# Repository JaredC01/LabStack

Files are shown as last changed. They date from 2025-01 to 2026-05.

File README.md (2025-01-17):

# LabStack
Modular rackmount solutions for Raspberry Pi's and other SBC's and accessories.

#### Hey Everyone!
Just to keep everyone in the loop, I will continue to work on uploading instructions and images as I have time.  In the meantime, all of the current STLs are available!

**NOTE: Additional hardware IS required for most models.**

Here's a short list of hardware off the top of my head:
* 2U Printed Bracket - Requires 16x M3x4x5mm Brass Heatset Inserts, 4x M3x6mm (or other M3x6mm thru M3x20mm) screws per module (BHCS or SHCS, no FHCS).
* 1U 5.25" Drive Bay Mount (designed specifically for the Icy Dock ExpressCage MB324SP-B) - Requires 8x M3x6mm screws (BHCS or SHCS, no FHCS).
* General Pi Mounts (2x Pi, 1x Pi, etc.) - Requires 4x M2.5x5 SHCS screws.  If using a HAT (PoE or otherwise), standoffs and/or other length M2.5 screws may be required.
* JetKVM Modules - Requires 2x M2x12 SHCS screws per JetKVM unit.
* 80mm Fan Panel - Requires the coarse-thread screws that the fans come with.

**I am open to helping create mounts for specific models within reason, but will be releasing CAD for users to create their own mounts!  The possibilities are endless!**

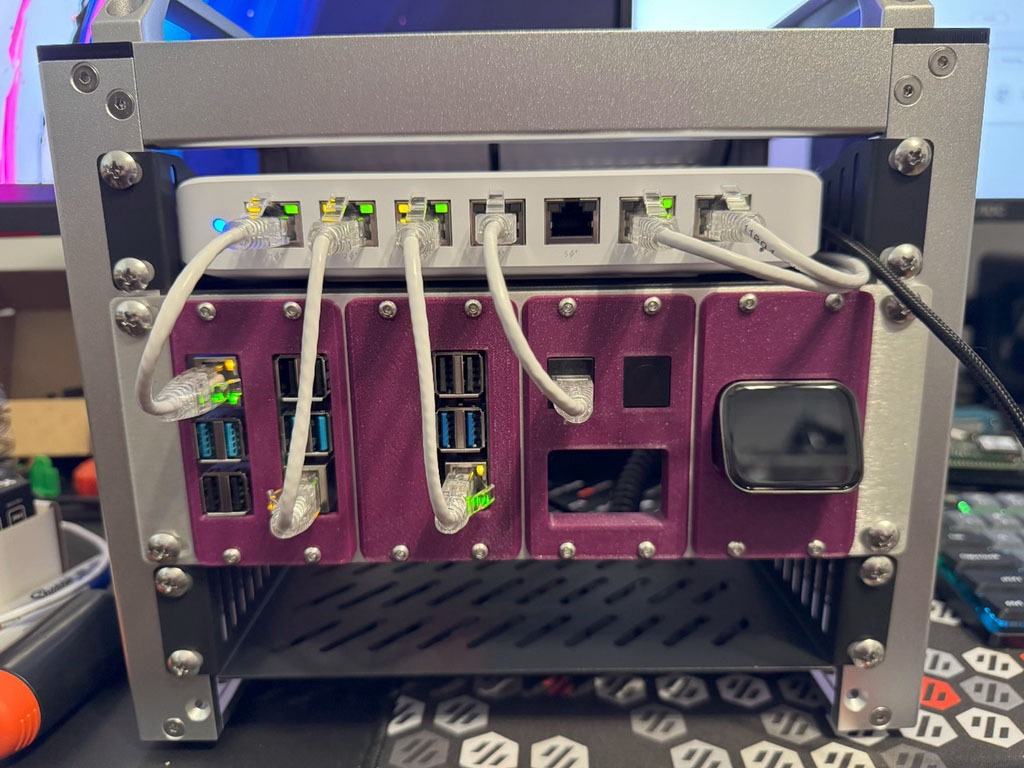
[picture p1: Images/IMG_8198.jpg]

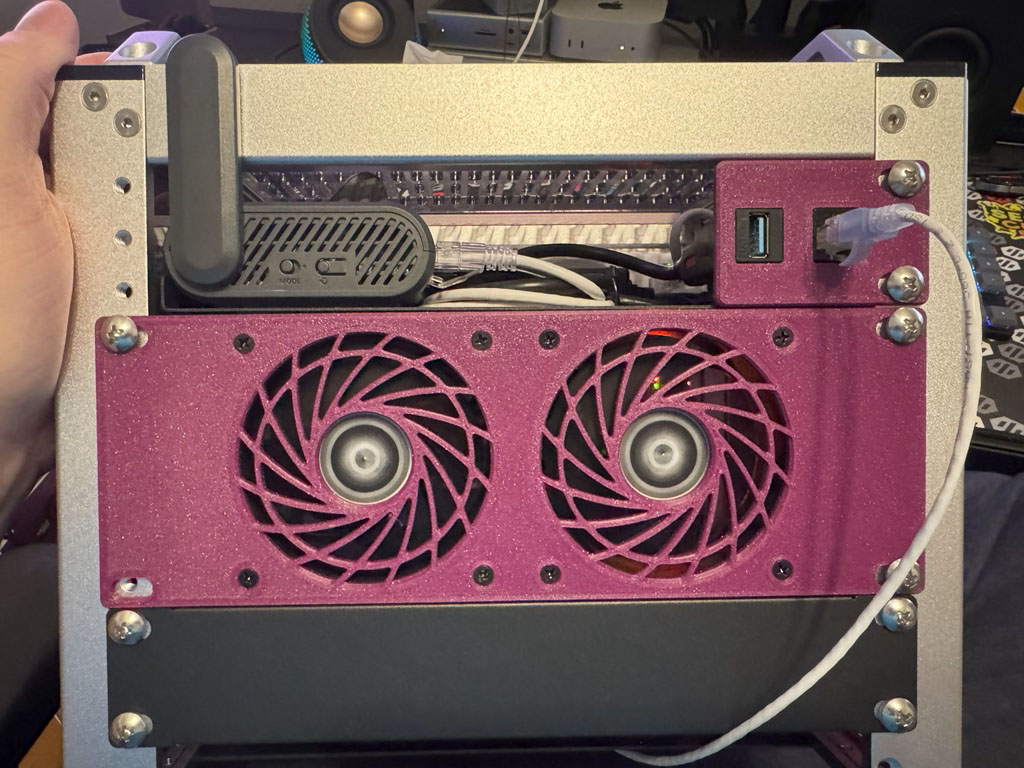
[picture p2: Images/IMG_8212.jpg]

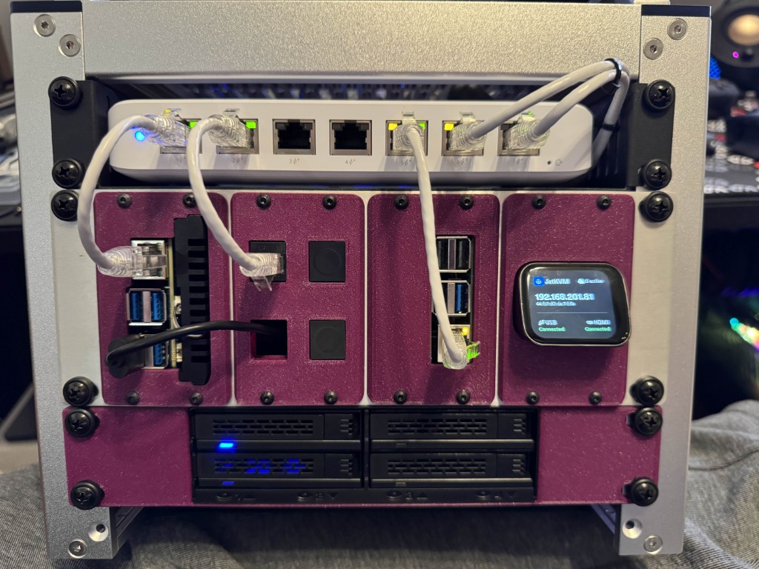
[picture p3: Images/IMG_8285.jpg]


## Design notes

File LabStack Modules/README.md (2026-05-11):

# LabStack Modules
This section of the repository contains 3D models of items that mount into LabStack *brackets* (see the [LabStack 19](https://github.com/JaredC01/LabStack/tree/main/LabStack%2019) and [LabStack Mini](https://github.com/JaredC01/LabStack/tree/main/LabStack%20Mini) sections in the directory above this one). Each module consumes a single slot in those brackets, allowing up to four modules (eight in a 19" rack) to be mounted side-by-side while requiring only 2U of height. A brief description of each item is given in the following tables:

## STLs

| **File** | **Description** | **Hardware Required** |
| :--- | :--- | :--- |
| `Module 1x JetKVM 1x Keystone 90 Degree.stl` | Mounts a JetKVM + one keystone slot | Two M2 x 16mm SHCS |
| `Module 1x JetKVM 2x Keystone.stl` | Mounts a JetKVM + two keystone slots | Two M2 x 16mm SHCS |
| `Module 1x JetKVM.stl` | Mounts a JetKVM | Two M2 x 16mm SHCS |
| `Module 1x JetKVM with Logo.stl` | Mounts a JetKVM. Has embossed logo at rack face | Two M2 x 16mm SHCS |
| `Module 1x Pi 1B Rev 2.0.stl` | Mounts one old-school Raspberry Pi 1 Model B | Two M2 screws, two M2 nuts |
| `Module 1x Pi 5 with Pimoroni NVMe Base.stl` | Mounts one Pi 5 with the [Pimoroni NVMe Base](https://shop.pimoroni.com/products/nvme-base) underneath | Hardware from Pimoroni kit |
| `Module 1x Pi 5 with Pimoroni NVMe Base Tall.stl` | Same as above, but allows using the taller standoffs to put the Pi "higher" above the base | Same as above |
| `Module 1x Pi 5 with WisdPi 5Gbps HAT.stl` | Mounts one Pi 5 with the [WisdPi 5GbE PoE Hat](https://www.wisdpi.com/products/wp-nh5000p) | Hardware from WisdPi kit |
| `Module 1x Pi with 25 SSD.stl` | Mounts one Pi and one 2.5" SSD (max 9mm thick) underneath. SDD's SATA ports are exposed at rack face | Four M3 screws, four M2.5 screws + heatsets |
| `Module 1x Pi with 2x Keystone.stl` | Mounts one Pi + two keystone slots | Four M2.5 screws + heatsets |
| `Module 1x Pi with HAT.stl` | Mounts one Pi, has a blank panel to be modified for any HAT | Four M2.5 screws + heatsets |
| `Module 1x WaveShare CM4-IO-BASE with HAT.stl` | Mounts one Pi CM4 in the [WaveShare Mini Base Board](https://www.waveshare.com/wiki/CM4-IO-BASE-B) | Hardware from WaveShare kit |
| `Module 2x 25 SSD.stl` | Mounts two 2.5" drives, with their SATA ports exposed at rack face | Four M3 screws per drive |
| `Module 2x JetKVM.stl` | Mounts two JetKVM units in a single module | Four M2 x 16 SHCS |
| `Module 2x Keystone.stl` | A blanking plate with two keystone slots | None |
| `Module 2x Keystone with Passthru.stl` | A blanking plate with two keystone slots and a generic pass-through opening | None |
| `Module 2x Pi.stl` | Mounts two Raspberry Pis, without additional fans (see subsection below) | Eight M2.5 screws, four M 2.5 heatsets |
| `Module 3x 25 SSD.stl` | Mounts three 2.5" drives, with their SATA ports exposed at rack face. Maximum thickness ~9mm per drive | Four M3 screws per drive |
| `Module 4x Keystone.stl` | A blanking plate with four keystone slots | None |
| `Module Blank.stl` | A completely blank plate. Can be modified for custom designs | None |
| `Module WaveShare 2.8in DSI Display.stl` | Mounts the [WaveShare 2.8" DSI Display](https://www.waveshare.com/wiki/2.8inch_DSI_LCD) | Liquid/gel adhesive (optional) |

## STLs/Module 2x Pi with Fan

This module assembly mounts two Raspberry Pis (any modern Pi with a "B" footprint should fit) in a single module slot, along with blower fan(s) to increase airflow across them.

| **File** | **Description** |
| :--- | :--- |
| `Module 2x Pi with Fan.stl`  | Main body. Includes mount points for a fan bracket (below) |
| `4010 Axial Mount.stl` | Mounts a single 40x10mm blower fan such that it blows air for both Pis |
| `Dual 3007 Blower Mount.stl` | Mounts one 30x7mm blower fan for each Pi |
| `Dual 4010 Blower Mount.stl` | Mounts one 40x10mm blower fan for each Pi |

## STLs/Module Radxa X4

This module assembly mounts a [Radxa X4](https://radxa.com/products/x/x4) mini-PC. Required hardware:
 - The X4 and its included heatsink/blower fan (but not the leg frame that comes attached)
 - Four M2.5 x 25mm socket-headed cap screws (SCHS)
 - One 3D printed body (top row of table below) 
 - Four 3D printed spacers (see table below)
 - (Optional) Power-over-Ethernet hat

The module is assembled as a stack, listed from bottom to top here: printed body, PoE hat (if present), printed spacer, X4, heatsink/blower fan. The printed spacer should be used on the screw that is farthest from the rack face, closest to the L-shaped shelf of the printed body. Screw through the stack and into the heatsink's tapped holes.

| **File** | **Description** |
| :--- | :--- |
| `Module 1x Radxa X4 with Heatsink.stl` | Main body. Includes a hexagonal cutout for PoE hat's fan |
| `Radxa X4 NO PoE HAT Spacer.stl` | Spacers to use when NOT using PoE hat |
| `Radxa X4 WITH PoE HAT Spacer x4.stl`  | Spacers to use when PoE hat is installed |

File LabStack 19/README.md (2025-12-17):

# Labstack 19
This section of the repository contains models of items that mount directly to a **full-width** (19") rack. Currently, the only item inside is `DXFs/2U 19 Lasercut Bracket.dxf`, which is a 2D design for a bracket to be laser- or plasma-cut. It is 2U tall and can hold a total of **eight** "LabStack Modules" (see the [Modules](https://github.com/JaredC01/LabStack/tree/main/LabStack%20Modules) section in the directory above this one).

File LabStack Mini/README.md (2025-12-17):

# LabStack Mini System
This section of the repository contains 3D models of items that mount directly to a half-width (10") mini-rack. The most important is probably the **Brackets** directory, which has several modules that can each accept four "LabStack Modules" (see the [Modules](https://github.com/JaredC01/LabStack/tree/main/LabStack%20Modules) section in the directory above this one). A simple description of each file in that folder is given in the following table:

## Brackets

| **File** | **Description** |
| :--- | :--- |
| `DXFs/2U Mini Lasercut Bracket.dxf` | A 2D design for a bracket to be laser-cut instead of 3D-printed. |
| `STLs/2U Mini 4x LabStack Module M3 Nut Bracket.stl` | Full-width 3D printable bracket that uses standard M3 hex nuts (4/module). |
| `STLs/2U Mini 4x LabStack Module M3x3x4.6mm Heatset Bracket.stl` | Full-width 3D printable bracket that uses M3x3x4.6 heatset inserts instead of nuts. |
| `STLs/2U Mini 4x LabStack Module M3x4x5mm Heatset Bracket.stl` | Full-width 3D printable bracket that uses M3x4x5 heatset inserts instead of nuts. |
| `STLs/2U Mini Split 4x LabStack Module Bracket x2.stl` | Half-Width 3D printable bracket for smaller printers. Requires 2x printed parts and heatsets. |

## Accessories

The **Accessories/STLs** directory contains rack-mount options for items that may not fit in a module as easily, such as larger Mini-PCs, or for alternate companions for the `2U Mini Split 4x LabStack Module Bracket x2.stl` described above ("half-width brackets"). All items in this table are 3D printable.

| **File** | **Description** |
| :--- | :--- |
| `1.5U Mini 1x M4 Mac Mini with 1x LabStack Bracket Left.stl`  | A 1.5U bracket that holds an M4 Mac Mini (left) with a LabStack module (horizontal). |
| `1.5U Mini 1x M4 Mac Mini with 1x LabStack Bracket Right.stl` | A 1.5U bracket that holds an M4 Mac Mini (right) with a LabStack module (horizontal). |
| `1U Mini 2x Keystone 2x SMA Left Mount.stl` | A half-width bracket for 2x keystone slots nearest the rail, 2x SMA ports by center. |
| `1U Mini 2x Keystone 2x SMA Right Mount.stl` | Same as above, but can be mounted on opposite rail without keystones upside-down. |
| `1U Mini 2x Keystone Left Mount.stl` | A **quarter-width** bracket for 2x keystone slots. Useful for cable management. |
| `1U Mini 2x Keystone Right Mount.stl` | Same as above, but can be mounted on opposite rail without keystones upside-down. |
| `1U Mini 525 Drive Bay Mount.stl` | A full-width bracket with a single 5.25" drive bay, such as for a CD or DVD drive. |
| `1U Mini Blank Panel.stl` | A full-width blanking panel. Can be used to manage airflow/aesthetics, or base for new designs. |
| `2U Mini 2x 80mm Fan Panel.stl` | 2U full-width blanking panel, with holes and a grate for mounting two 80mm fans. |
| `M4 Mac Mini Spacer x2.stl` | A companion piece for the M4 Mac Mini brackets (top two rows), supports top/bottom shelves. |
| `Split Bracket Brace x2.stl` | A companion piece for half-width brackets, used to join two halves together. |

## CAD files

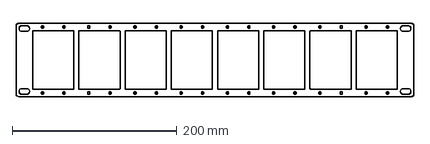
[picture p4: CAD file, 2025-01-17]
LabStack 19/Brackets/DXFs/2U 19 Lasercut Bracket.dxf
482.6 x 89.0 mm

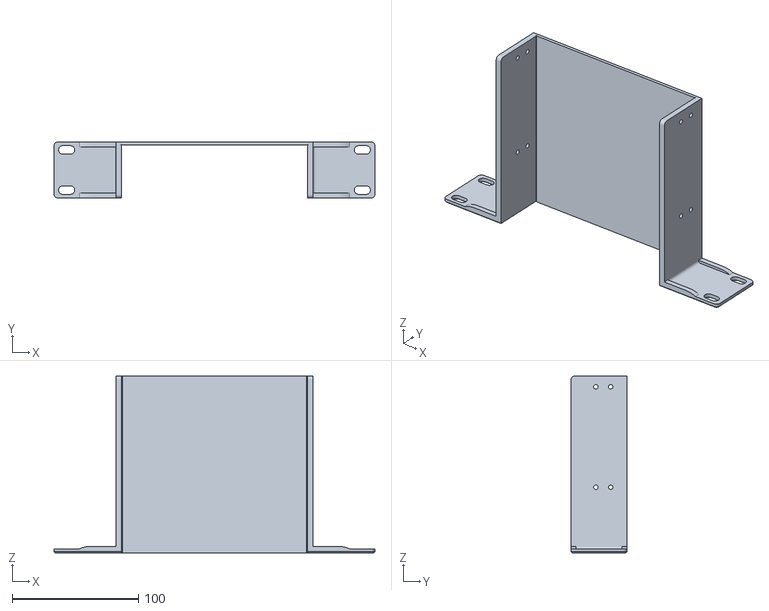
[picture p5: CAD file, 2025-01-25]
LabStack Mini/Accessories/STLs/1U Mini 525 Drive Bay Mount.stl
254.0 x 44.4 x 140.0

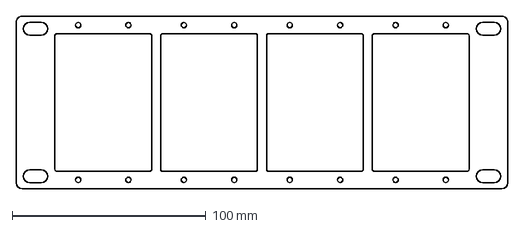
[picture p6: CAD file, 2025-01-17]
LabStack Mini/Brackets/DXFs/2U Mini Lasercut Bracket.dxf
254.0 x 89.0 mm

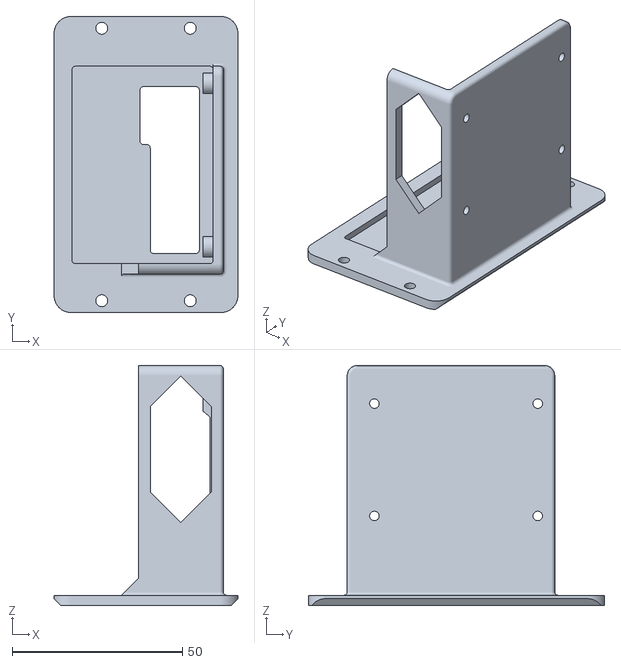
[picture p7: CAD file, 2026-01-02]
LabStack Modules/STLs/Module 1x Waveshare 30915.stl
54.0 x 87.0 x 70.5

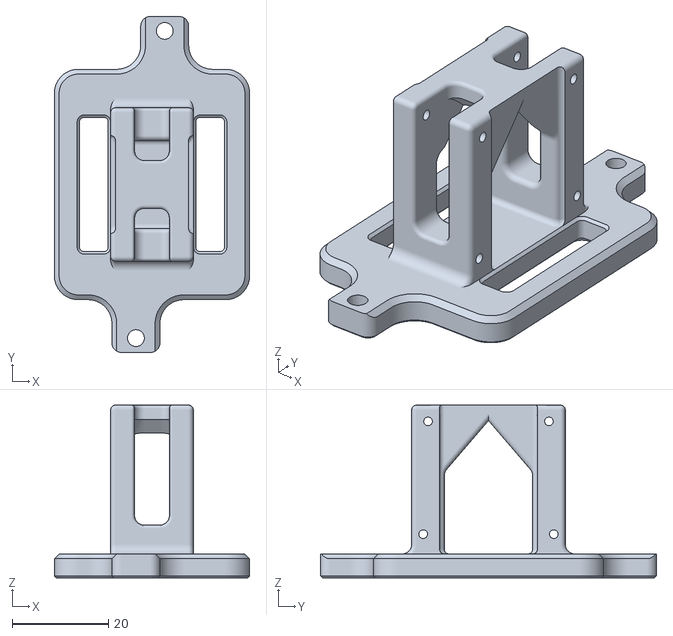
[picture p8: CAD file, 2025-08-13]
LabStack Modules/STLs/Module 2x Pi with Fan/Dual 3007 Blower Mount.stl
40.7 x 70.0 x 36.0

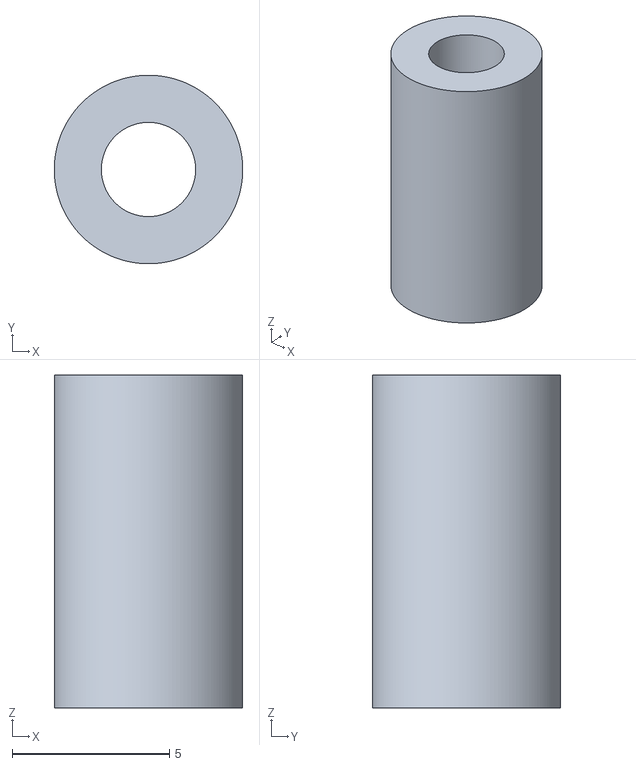
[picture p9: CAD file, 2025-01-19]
LabStack Modules/STLs/Module Radxa X4 with Heatsink/Radxa X4 NO PoE HAT Spacer x4.stl
6.00 x 6.00 x 10.6

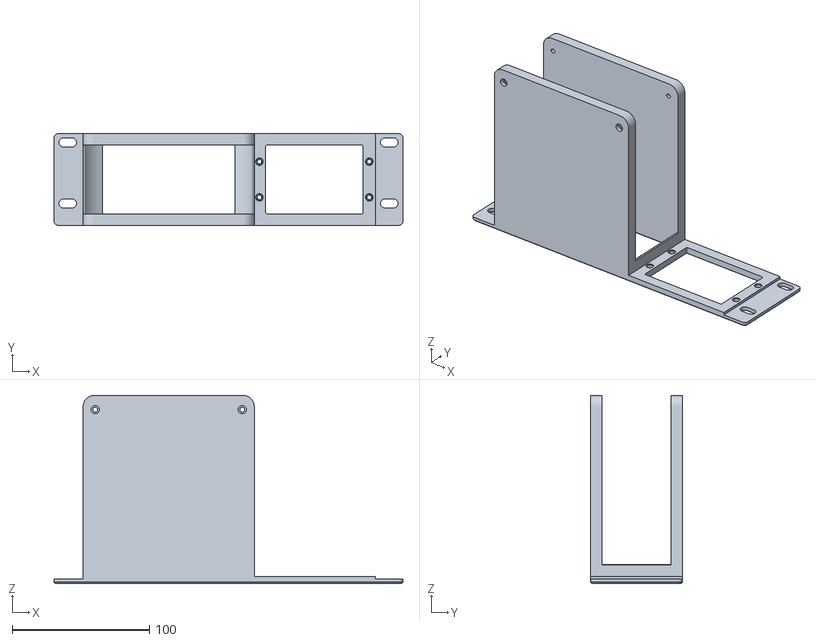
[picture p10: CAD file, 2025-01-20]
LabStack Mini/Accessories/STLs/1.5U Mini 1x M4 Mac Mini with 1x LabStack Bracket Right.stl
254.0 x 66.7 x 137.0

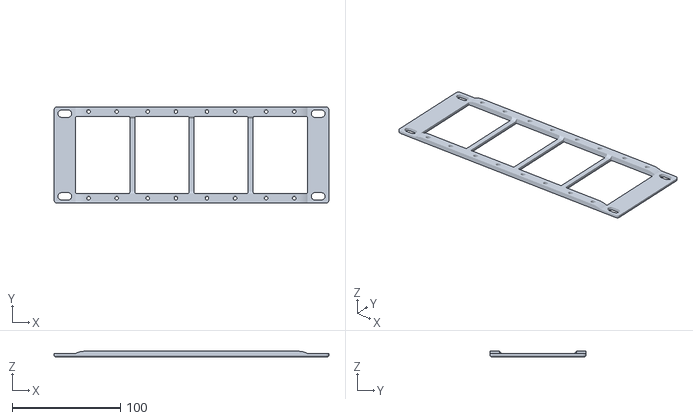
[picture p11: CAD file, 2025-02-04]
LabStack Mini/Brackets/STLs/2U Mini 4x LabStack Module M3x3x4.6mm Heatset Bracket.stl
254.0 x 89.0 x 5.20

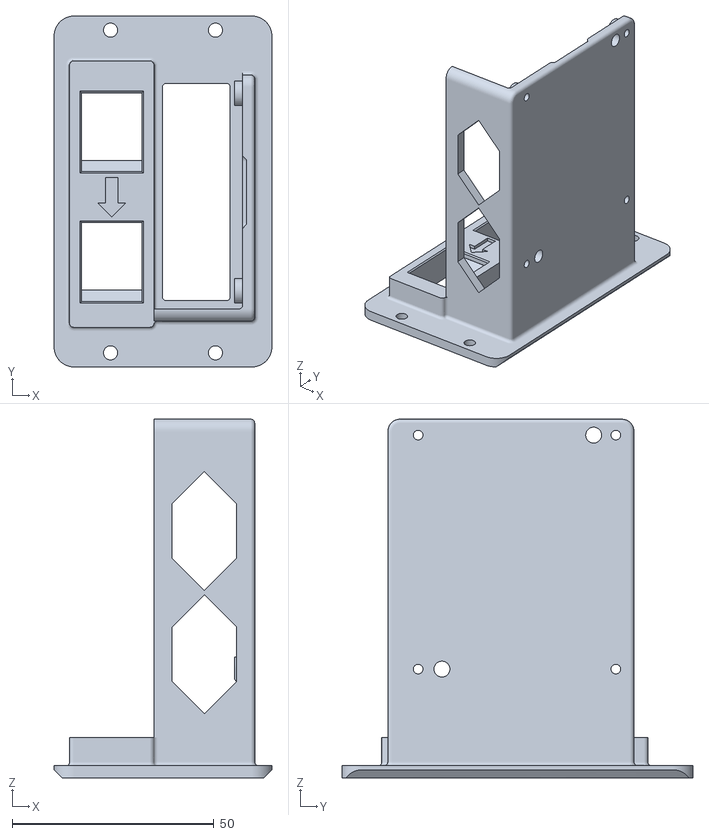
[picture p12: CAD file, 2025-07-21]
LabStack Modules/STLs/Module 1x Pi with 2x Keystone.stl
54.0 x 87.0 x 88.9

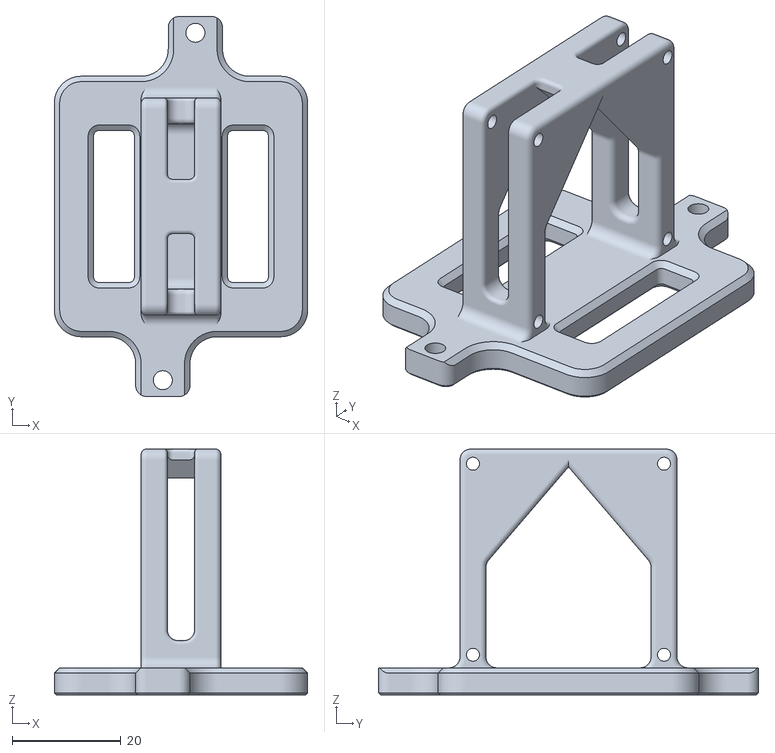
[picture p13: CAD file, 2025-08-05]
LabStack Modules/STLs/Module 2x Pi with Fan/Dual 4010 Blower Mount.stl
46.7 x 70.0 x 45.3

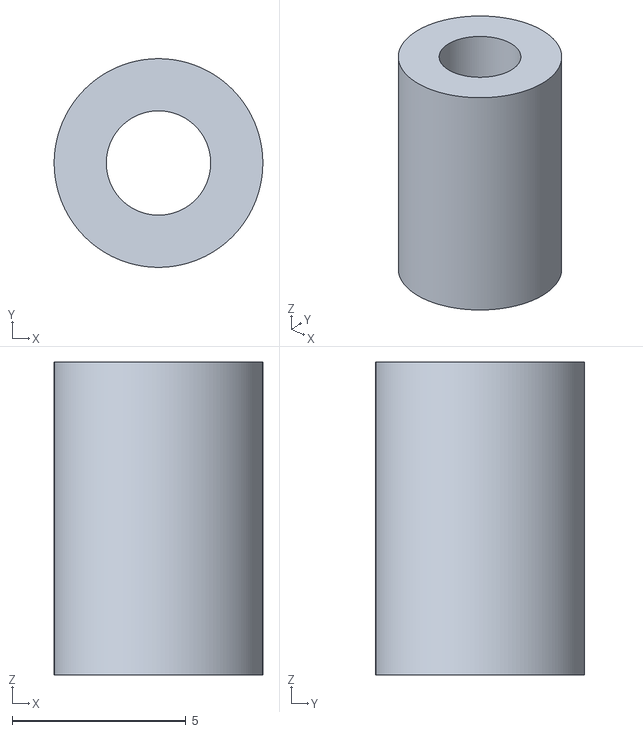
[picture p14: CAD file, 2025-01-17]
LabStack Modules/STLs/Module Radxa X4 with Heatsink/Radxa X4 WITH PoE HAT Spacer x4.stl
6.00 x 6.00 x 9.00

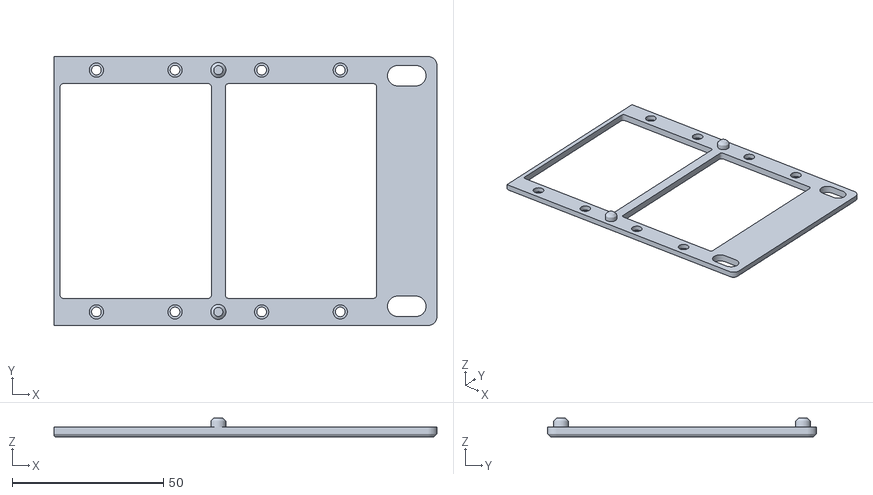
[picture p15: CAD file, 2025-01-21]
LabStack Mini/Brackets/STLs/2U Mini Split 4x LabStack Module Bracket x2.stl
126.7 x 89.0 x 6.20

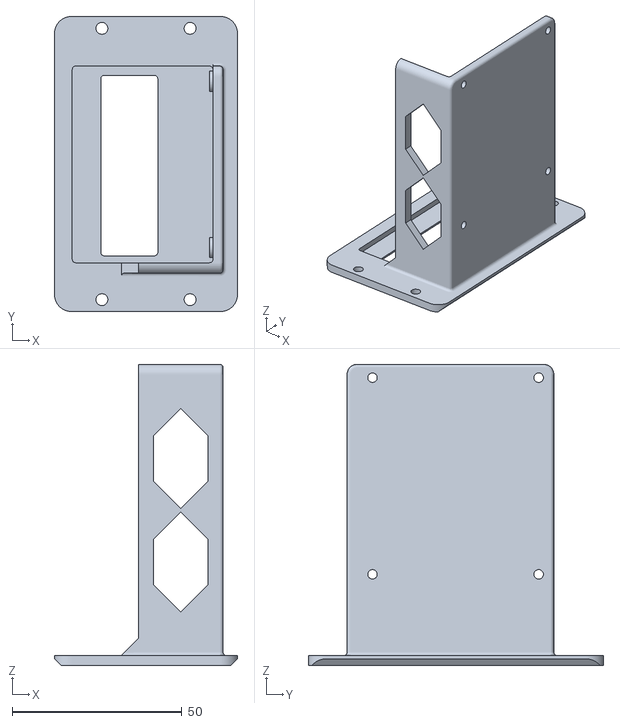
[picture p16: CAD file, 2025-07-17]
LabStack Modules/STLs/Module 1x Pi 5 with Pimoroni NVMe Base Tall.stl
54.0 x 87.0 x 88.9

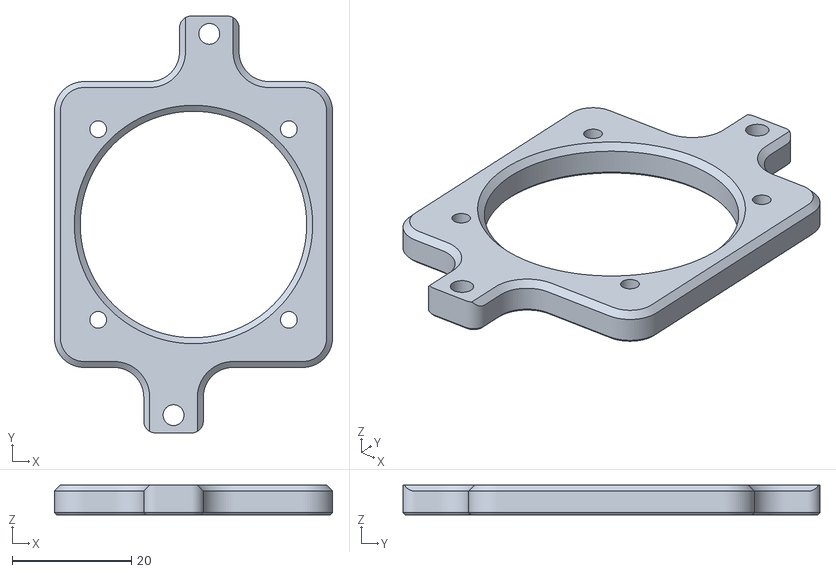
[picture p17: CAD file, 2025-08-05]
LabStack Modules/STLs/Module 2x Pi with Fan/4010 Axial Mount.stl
46.7 x 70.0 x 5.00

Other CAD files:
LabStack Mini/Accessories/STLs/1.5U Mini 1x M4 Mac Mini with 1x LabStack Bracket Left.stl
LabStack Modules/STLs/Module Radxa X4 with Heatsink/Module 1x Radxa X4 with Heatsink.stl
LabStack Mini/Accessories/STLs/M4 Mac Mini Spacer x2.stl
LabStack Mini/Brackets/STLs/2U Mini 4x LabStack Module M3x4x5mm Heatset Bracket.stl
LabStack Mini/Accessories/STLs/1U Mini 2x Keystone 2x SMA Left Mount.stl
LabStack Mini/Accessories/STLs/1U Mini 2x Keystone 2x SMA Right Mount.stl
LabStack Mini/Accessories/STLs/1U Mini 2x Keystone Left Mount.stl
LabStack Mini/Accessories/STLs/1U Mini 2x Keystone Right Mount.stl
LabStack Mini/Accessories/STLs/1U Mini Blank Panel.stl
LabStack Mini/Accessories/STLs/2U Mini 2x 80mm Fan Panel.stl
LabStack Mini/Accessories/STLs/Split Bracket Brace x2.stl
LabStack Mini/Brackets/STLs/2U Mini 4x LabStack Module M3 Nut Bracket.stl
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

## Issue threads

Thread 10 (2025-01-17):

module suggestion

ConanWolf46, 2025-01-17:
https://www.amazon.com/dp/B01J705MTC?ref=ppx_yo2ov_dt_b_fed_asin_title&th=1

this amazon product is a sim data to USB for internet via phone service, there is a version of the product on aliexpress as well however i only linking amazon because idk how people feel about aliexpress on here, the version on aliexpress is 9 USD.

the module idea that i was having was similarly to the antenna coming out of the back but for the device, the USB port on the device is in the front (antenna is in the back) making it perfect for that 4 hole module setup that you have already

JaredC01, 2025-01-17:
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

Just so I'm clear, you're looking for a way to mount this device in a module at the front of the LabStack, correct?  Are you wanting to break out the USB port as well via Keystone Jack?

bemany, 2025-01-21:
Request for Intel Nuc BOXNUC8i5BEK2

I am not able to find a simple solution for mounting the nuc on its mounting screws on a 10" module

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
https://www.intel.com/content/www/us/en/support/articles/000006857/intel-nuc/intel-nuc-kits.html

It would also be nice to ziptie the power adapter next to it "huntkey HKA09019047-6u"
https://www.ebay.de/itm/256636100141

Break out of HDMI, Keystone .. is not mandatory

ConanWolf46, 2025-02-16:
hay sorry for not responding for a bit, ideally yes because this device requires a USB connection and the goal is for a raspberry pi server over a phone network

ConanWolf46, 2025-02-16:
after the pi gets the network via the device, i could if i wanted to split the network off to multiple other pis if needed or just have the one pi as needed.

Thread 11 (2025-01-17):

ODroid-H2/3/4

jar349, 2025-01-17:
I have a bunch of the [H-series odroids (H2, H3, H4)](https://www.hardkernel.com/shop/odroid-h4/) that it would be awesome to mount into a 10" mini-rack!

I'm opening this issue to see if others would also be interested.

JaredC01, 2025-01-17:
With the size on these being 120mm x 120mm, they would need to be in a full 1U mount rather than a module.  As with the Zimaboard, I could make one with a JetKVM mount included, but that's probably the only option available for it.

jar349, 2025-01-25:
With 1U of space, 10" wide, I wonder if two odroids could be mounted side by side?

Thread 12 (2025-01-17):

Module for RPI 1

oNutti, 2025-01-17:
Hello,
I currently run RPI 4, RPI 1 and a switch, and half a patch panel. This project is perfect for me, i would just love to have a mount for RPI 1.

JaredC01, 2025-01-17:
Does the RPi 1 not use the same mount as the rest of the Pi's?  I'm not familiar with the older Pi's, but I thought they shared the same form factor as the newer ones.  A single 2x Pi mount should fit both your Pi 4 and your Pi 1 (with 3 modules open for other things).

oNutti, 2025-01-17:
> Does the RPi 1 not use the same mount as the rest of the Pi's? I'm not familiar with the older Pi's, but I thought they shared the same form factor as the newer ones. A single 2x Pi mount should fit both your Pi 4 and your Pi 1 (with 3 modules open for other things).

Unfortunately, not. The RPI 1 (maybe 2?) uses other mounting holes, actually only two. The 3, 4, 5 (maybe 2) uses the same holes. It's one of the dumbest things, they made..

oNutti, 2025-01-17:
Yes, the RPI 1 is can't be more outdated, but i still use it for hosting local controllers - someone other than me, might also use it, haha.

JaredC01, 2025-01-17:
I'm guessing it's more to do with the model "B" being the same (it looks like there's a Pi 1 Model B that looks to be the same as the rest). Do you have a picture of the Pi 1 you have for reference to know what I'm looking for?

oNutti, 2025-01-17:
The RPI 1 model B+ use the same mounting holes as the other ones, but funny enough does the RPI 1 use some other ones.

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

JaredC01, 2025-01-17:
Too many letters and pluses! 🤣

I should be able to find a model for that Pi 1 and add a mount for it, but I don't expect I'll be able to make it work with a dual-Pi mount (meaning it would be a single module unit). So long as that's not an issue, I'll add it to the list!

oNutti, 2025-01-17:
> Too many letters and pluses! 🤣
>
> I should be able to find a model for that Pi 1 and add a mount for it, but I don't expect I'll be able to make it work with a dual-Pi mount (meaning it would be a single module unit). So long as that's not an issue, I'll add it to the list!

Not a problem. I only use two atm, and dont plan on more than 3, so perfect!
Thanks!

oNutti, 2025-01-18:
Hello again,
Just wanted to mention, that the RPI 1 also use the big SD card, and not the microSD cards.
Thanks for this nice project, once again!

oNutti, 2025-01-28:
Hey,
Just wanted a status. Any updates?

JaredC01, 2025-01-28:
Still on the list!  I've been sorting out some of the other modules that didn't need a full-custom design.  I may have some time tomorrow to get it sorted, otherwise it will likely be Thursday or Friday.

oNutti, 2025-01-28:
Sounds perfect!

JaredC01, 2025-01-30:
Okay, I've got a "preliminary" module created... It's specifically for the Pi 1 Model B Rev 2.0 (which is the version of the Pi 1 B that has mounting holes, apparently).  Please let me know if it works!

https://github.com/JaredC01/LabStack/blob/main/Modules/STLs/Module%201x%20Pi%201B%20Rev%202.0.stl

oNutti, 2025-01-30:
Perfect,
Printer is busy for the next hours. But i will write a review later
Many thanks

JaredC01, 2025-01-30:
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

I'll add another millimeter on the top and bottom for the little "clamps". Can you check with something plugged in to see if they go out further than 1mm on either side?

Other than that does it fit?

oNutti, 2025-01-30:
It fit perfectly. For you information, it would require 1 milimeter on every side.
" Can you check with something plugged in to see if they go out further than 1mm on either side?", not sure what you mean with this. Plugging in a usb or two, doesn't do anything to the mount at all.

JaredC01, 2025-01-30:
> It fit perfectly. For you information, it would require 1 milimeter on every side. " Can you check with something plugged in to see if they go out further than 1mm on either side?", not sure what you mean with this. Plugging in a usb or two, doesn't do anything to the mount at all.

Oh you mean the "winglets" on the USB plug itself.  I thought you meant the little spring metal pieces on both the top/bottom and sides and helps hold the plug when you plug in the USB port (visible in your picture above).  I'll add some clearance there on the sides, and see about chamfering the ethernet port a bit for helping with inserting/removing ethernet.

oNutti, 2025-01-30:
Github was down.. 😅
I will reprint it - my dad got a RPI 1, he can get it installed into my rack then

oNutti, 2025-01-30:
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
My now fully completed rack (lying, always things to upgrade..)
Second prototype works perfect.

JaredC01, 2025-01-31:
Awesome!  Thank you for the testing and feedback, I'll close the issue!

Closed 2025-01-31.

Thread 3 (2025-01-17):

STEP files please!

sirtimbly, 2025-01-17:
It's much easier to integrate these into my own designs if I have step files to import instead of STLs. Thanks! I'm looking forward to playing with this.

JaredC01, 2025-01-17:
STEP and F3D files will be available soon, I just need to clean up the CAD!  I should have an update this weekend with any luck.

Astrobirder, 2025-01-17:
Thank you ahead of time for the F3Ds & STEP formats!

JaredC01, 2025-01-18:
I've added the F3D CAD file for now.  The STEP file I exported was 180MB due to what I assume are the Pi and Radxa board models, so it's not able to be uploaded to GitHub without moving to a LFS repo (which I don't need to do otherwise).  I'll work on exporting another version without the board models later tonight.

JaredC01, 2025-01-31:
Updated F3D file uploaded, and compressed STEP file uploaded.  I simplified all of the Pi and board models as much as possible, and still ended up with a 230MB STEP file.  Fortunately STEP files are text-based, so I just ZIP'd the STEP to compress it.

Closed 2025-01-31.

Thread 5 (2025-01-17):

Module STL for 1x Pi + 2.5 SSD

DocBrown101, 2025-01-17:
Great project!

Could we get a module for 1x Pi & 2.5 SSD please?

JaredC01, 2025-01-17:
Jeff and I talked about a standalone 2.5" drive module, which is on the roadmap.  I can definitely make a Pi + SSD option, though it will have a tight bend radius if you're tying to install a USB to SATA adapter in the same slot as the Pi next to it.  So long as you're aware of the limitations, I don't mind adding it!

DocBrown101, 2025-01-17:
That would be really great. Thank you!

JaredC01, 2025-01-19:
I've added a Pi + 2.5" SSD option, available here: https://github.com/JaredC01/LabStack/blob/main/Modules/STLs/Module%201x%20Pi%20with%2025%20SSD.stl

I haven't tested it yet, but it should work without issue.  I'll print one once a printer frees up for testing, but please test it on your end as well!

> That would be really great. Thank you!

JaredC01, 2025-01-20:
Update: Tested and working!

Closed 2025-01-19.

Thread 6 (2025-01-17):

Feature request

monkeymademe, 2025-01-17:
Awesome project! I am looking forward to put this into my DeskMate

Would it be possible to have a broken down 2U Rack plate.... My poor Ultimaker 3 is falling a little short

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

JaredC01, 2025-01-17:
You can try splitting the model in the slicer, but I also just got an idea on how I can split the front plate, then reinforce it with the rear braces, in a 4-piece option (left half, right half, 2x braces).  It may need some glue, but the heatsets should act as a means of attachment as well.

I'll add it to my list!

monkeymademe, 2025-01-17:
Awesome thanks that would be helpful (also sorry I forgot to finish the title to this request)

JaredC01, 2025-01-18:
I've added 2 new files located here: https://github.com/JaredC01/LabStack/tree/main/LabStack%20Mini/STLs

The files are labeled as 2U Mini Split Printed Bracket Brace x2, and 2U Mini Split Printed Bracket x2.  You will (as the name implies) print 2 of each of those.

For assembly, line up the split halves, then attach the two brackets over the locating pins.  With the brackets on the locating pins, install the Heatset inserts for each of the screw holes.  There's enough overlap that you should get good support, but you might use some CA glue (super glue) between the brackets and the braces just as a precaution.

Please let me know how printing and assembly goes; you're the guinea pig for testing!

markafarrell, 2025-01-21:
Fyi I printed this out on an Ender 3 and it worked fine.

It could probably use a little clearance between the two halves as they interfered slightly causing the piece to bow upwards. I just clamped it down between two pieces of wood while the CA glue set and it looks fine.

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

JaredC01, 2025-01-21:
I had added some clearance between them, but it looks like that somehow worked its way back out of the final version (I probably reverted something that broke it).

I've added clearance back (total of 0.4mm, or 0.2mm per side) so it SHOULD be good to go at this point!

markafarrell, 2025-01-21:
Printing the revised version now. Will report back when it's done.

markafarrell, 2025-01-21:
Another thing that might be nice is 4 alignment pins per half instead of 2. I think it will make it a bit easier to make sure things are square when assembling

markafarrell, 2025-01-21:
The STL also appears to be flipped now (alignment pins pointing down) which caught me out cause it needed to be flipped in the slicer

JaredC01, 2025-01-21:
> The STL also appears to be flipped now (alignment pins pointing down) which caught me out cause it needed to be flipped in the slicer

Fixed and pushed.  As far as locating pins goes, two was what fit without running into issues... I can probably add one more set of pins right in the middle where they meet, so each half uses half of the hole.  I'll see what that looks like in CAD.

markafarrell, 2025-01-21:
I was thinking something like.

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

JaredC01, 2025-01-21:
That would end up pretty severely compromising the integrity of the braces, and since they're only used as guides, I don't think the tradeoff is worth it there.

markafarrell, 2025-01-21:
An alternative would be to have one of the pins on the brace instead of a hole.

markafarrell, 2025-01-21:
Actually I think then you wouldn't be able to print the tapered ends of the braces

markafarrell, 2025-01-21:
P.s. the revised version with more clearance works great

JaredC01, 2025-01-24:
> P.s. the revised version with more clearance works great

Good deal!  As far as the extra pins goes, I looked at adding the middle pins that I had talked about, and I don't like it as it leaves too much wiggle room with the gap between the parts.  The heatset inserts will help align the parts, along with the pins, so I think I would prefer to leave it as-is until there's feedback from others.

I'll leave the issue open until I hear a bit more feedback.

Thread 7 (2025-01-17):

Module for Zimaboard

koreyrebello, 2025-01-17:
Great work - thank you for putting this all together! Any possibility of creating a module for a Zimaboard 832?

JaredC01, 2025-01-17:
Not likely able to do a module for the Zimaboard due to the width of the unit. The spec width is 81mm from what I've been told, while the opening in the LabStack Mini is only 71mm.

I don't have a Zimaboard here to test / verify fit, but if you're able to print the 2U bracket and check fitment, please let me know. If it DOES somehow fit, I certainly don't mind making a module!

I've also proposed a 1U enclosure option that would incorporate space for the PCIe slot and maybe a JetKVM here: https://github.com/JaredC01/LabStack/issues/2

ospfv11, 2025-01-17:
Thanks for the quick response @JaredC01 ! I will take a look at the measurements.

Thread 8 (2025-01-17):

Any plans for 19-inch racks?

itsCARLsanity, 2025-01-17:
Hey Jared,

I just saw Jeff's video, amazing work you got there. You got any plans to extending the bracket or whatever the modules are inserted into, to 19-inch racks? Possibly by modularising it by segments and using some kind of connection in between.

Thanks and have a good day!

JaredC01, 2025-01-17:
Yes! That's also why the repo is LabStack instead of just LabStack Mini. 😃

The 19" side I'll need to test to see if 3D printed parts will hold up well enough or if it needs laser-cut metal parts. Printing a full 19" 2U bracket would also take a pretty large bed, which rules out a lot of cheaper printers, so I'm leaning towards laser-cut metal (at least for the bracket).

itsCARLsanity, 2025-01-17:
That's good to hear! I initially thought its only for 10-inch racks since its primarily featured on Jeff's minilab video. Also, on his site it says "Labstack mini"

I would say, laser-cut metal (for the bracket) for 19-inch racks would limit people from trying out Labstack since  not everybody would have that kind of equipment or it could be pretty expensive. I think the 19 inch 3D printed bracket part would still be worth a while, at least for some it would be an option for them to try out.

JaredC01, 2025-01-17:
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

The 10" mini rack model is indeed called the LabStack Mini, so that makes sense!  The Mini is also where Jeff and I started with it for his specific mini rack project(s), but it's certainly not the end. 😃

For the laser-cut parts, you wouldn't be making those at home, you'd use a service like https://sendcutsend.com to have them made for a fee, then print the modules at home. The fee for a couple of the brackets from SendCutSend would likely be under $50 USD shipped, so for a project where you're putting in up to 10-12 Raspberry Pi's costing upwards of $500 or more total before you include any HATs, it doesn't seem unreasonable to spend for the laser-cut bracket(s).

Just to be clear, I'm not fully opposed to a printed option for the main bracket!  The concern is whether or not a printed bracket will be rigid enough to support the weight, because a fully-loaded 19" LabStack unit can be heavier than you would think.

I will definitely do some testing, but I fully expect that a printed bracket will not work well for the 19" version of LabStack. If that turns out not to be the case, I'll let you know!

JaredC01, 2025-01-17:
I just put together a 19" rack version of the main LabStack bracket; the total cost at Send Cut Send for two of them is $49, shipped.

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

This is obviously only applicable to the US, but does align with what my estimate was in my previous post.

eliasstepanik, 2025-01-21:
Just created a pull request for a 3D Printed version.

itsCARLsanity, 2025-01-26:
Hello~ sorry for late reply.

> For the laser-cut parts, you wouldn't be making those at home, you'd use a service like https://sendcutsend.com/ to have them made for a fee, then print the modules at home.

Lol. I thought you'd need a laser machine to do it, never knew there's a service for laser cutting metal. This is great then, although for me, I'd be paying more for shipping to get it from the US since I don't know if there's any kind of laser cutting service available from the country I'm in.

This is awesome work Jared. Thank you!

JaredC01, 2025-01-31:
Worth taking a look to see if you have a local laser-cutting company!  Closing the issue as resolved for now, but let me know if you need anything else!

Closed 2025-01-31.

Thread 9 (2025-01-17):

Contribute Picamera mount (single and double) and hyperpixel display mount

monkeymademe, 2025-01-17:
Hey there,

Again awesome project I also made some Rackmate mounts I would love to share with you if you would like them (or tips for improvement)

Its a little niche for cameras and display but I am sure someone is gonna need it

Files can be found here (don't know if you accept merge requests): https://github.com/monkeymademe/deskpi-rackmate-prints

Here it is in action

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

JaredC01, 2025-01-17:
Hey there!  Thanks for the link!  I happen to have a Pimoroni HyperPixel 4.0 sitting right next to me that I'm not doing anything with, so I may just have to find a use for it on the mini rack here.

One thing off the top of my head that you could do would be to angle the Pimoroni display out to keep it in the space of the single rack unit (1U), which would free up space in the rack unit below it.

What are you using the displays and the camera for?

monkeymademe, 2025-01-17:
Not sure what angle you mean? sticking out? I'll be honest its not a great solution and I used PLA which warped with the heat... At the moment it was just running the lcars server on a pi which synced to the bigger display. I am looking for another use tbh its living in the bedroom so its not on at the moment.

The cameras are for my tests with my other project https://github.com/monkeymademe/picamera2-WebUI Jeff has mentioned it before on a video

JaredC01, 2025-01-17:
Sticking out a bit, yes.  Basically think of it angled out at about 45 degrees from the top, which shrinks the overall profile.  The idea came from the way the Voron line of printers mounts the display to save space:

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

Gotcha on the use case!

monkeymademe, 2025-01-17:
Ha not bad... This version has the pi connected directly at the back so its a chunky setup. But with ribbon cable I would do something like that I think. I like the design you have... While Deskpi has metal and all I feel its wasting too much space and too restrictive on the orientation of the pi (maybe you want it ass backward?).

Anyways I digress I recently broke my v1 7inch display for the pi I would have liked to have that or well now the v2 model fitted to the front or above the system for system monitoring. Something I can kill the backlight too so it does dark.

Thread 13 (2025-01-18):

Radxa X4 - THANK YOU!

ssilverm, 2025-01-18:
Just wanted to say THANK YOU! for making a Radxa X4 mount.

I made this one for myself but I think I'm going to switch to yours instead.

https://makerworld.com/en/models/1006202#profileId-984656

-Shea

JaredC01, 2025-01-19:
Let me know how you like it!  There are currently two sets of spacers for the Radxa X4 mount; one for using a PoE HAT, and one for no PoE HAT.  Make sure you choose the appropriate spacer!

For reference, both sets of spacers are in the Modules / STLs folder with the prefix "Module Add".

Closed 2025-01-31.

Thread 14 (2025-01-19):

Slot for a 3.5in hdd and mounting holes for a 2.5in ssd

zachary234533532353335533461113466, 2025-01-19:

JaredC01, 2025-01-19:
> No description provided.

Hi Zachary!  Did you have more on this?  I would need some info in order to work with the idea.

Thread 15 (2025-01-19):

Add M4 Mac Mini 1.5U Mount with 1x LabStack Module

JaredC01, 2025-01-19:
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

 _Originally posted by @JaredC01 in [#56](https://github.com/geerlingguy/mini-rack/issues/56#issuecomment-2600975826)_

GarnetSunset, 2025-01-20:
Extremely excited and ill be watching this issue to test it out!

JaredC01, 2025-01-20:
Added to the repo and awaiting feedback.  Info referenced here: https://github.com/JaredC01/LabStack/issues/new/choose

JaredC01, 2025-01-20:
> Extremely excited and ill be watching this issue to test it out!

Mind reposting your info here?

For the power button; I knew it would be an issue, but I'm not sure of the best way to solve it yet. This will require a compound mechanism of some sort to change axis of motion for the button, but I'll lookin into it.

For the looseness, it looked like there was a pretty decent gap above your Mac Mini in the printed part... can you get me a close-up of that? I can adjust the height for the model, but was using someone else's CAD model.

JaredC01, 2025-01-20:
@GarnetSunset I updated the design a bit for the mount itself.  It's a bit thicker on the actual Mac mounting portion, and I adjusted the fit to be tighter top and bottom.  There's also new spacers that should physically touch the Mac Mini to keep it from moving anywhere.

The only concern I have with the design is that the layer lines for the Mac mount are in the weakest direction, which is why I added a bit more material, but I may look at adding a couple of separate flat sheets in the stronger direction to sandwich everything together.

If you don't mind printing another one, please let me know how the Mac fit is, and if it seems sturdy enough for the weight of the Mac!

GarnetSunset, 2025-01-20:
Wow! Thank you so much!! (Sorry I was out)

I'll give it a shot.... I'll print as draft to make it work nicely

(I'm planning on putting a jetkvm next to the m4 mac mini, and im wondering if the extension boards can do barrel plugs?)

But maybe a hole to push the power button manually? Just as a "in case of emergency" in the mean time?

For the record, my old message:
```
It's IN and it WORKS!

Two things that should *probably* be addressed perhaps:

1. The power button on the bottom left side is inaccessible, I realize this is apples fault not yours, but it *might* be important to people :) (not blaming you in the slightest!!)
2. Despite the spacers, it's not "snug" enough in there and can spin a lil and fall out!

Otherwise I love it!! Thank you Jared!
```
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

JaredC01, 2025-01-21:
Let me know how it goes this go around.  For the power button, I worry about adding a hole in a part that's already in the weak orientation...  Maybe I'll add a lever that comes out of the front somehow...

GarnetSunset, 2025-01-21:
Fits mUCH better! Much more snug.

JaredC01, 2025-01-21:
Awesome!  Any other feedback before I call it good?

GarnetSunset, 2025-01-22:
I like it! Only thing I would change is the button obviously :) I say its good!!

JaredC01, 2025-01-22:
I'll see what I can do for the button!

GarnetSunset, 2025-01-22:
Ah!! One thing, not *strictly* related, but would be nice, a rotated JetKVM mount for that spot so it's not going to be 90degrees?

GarnetSunset, 2025-01-22:
> [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@GarnetSunset](https://github.com/GarnetSunset?rgh-link-date=2025-01-22T20%3A30%3A52.000Z) Which model module did you used for the tp-link?

Dunno! Just grabbed a 10 inch mount for my tp SG108E

JaredC01, 2025-01-31:
> Ah!! One thing, not _strictly_ related, but would be nice, a rotated JetKVM mount for that spot so it's not going to be 90degrees?

Just coming back to this... I'll have one sorted for you shortly!

JaredC01, 2025-01-31:
> Woot!!!

Module added... Single JetKVM and single Keystone jack in a 90-degree module.  @GarnetSunset please let me know how it fits!

JaredC01, 2025-01-31:
> Thank you!!!! :)

You're welcome!  I expect a few pictures of both the updated Mac Mini mount, and the rotated JetKVM Module when it's done!

GarnetSunset, 2025-01-31:
Sir yes sir! I'm waiting for my Jetkvm unit still... But otherwise I'm super down!

customade, 2025-08-04:
Hi; I used this power button [3D print](https://www.printables.com/model/1074723-mac-mini-m4-power-button) and it works pretty well but it blocks off one of the stands.

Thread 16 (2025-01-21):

Module for Waveshare Mini Base Board (A/B)

shanduur, 2025-01-21:
Hi! First of all, thank you for making such an amazing project!

I came here with a request, for modules that will allow using Raspberry Pi Compute Modules (and other with the same format) in a LabStack using the following base boards / carrier boards.

## CM4 I/O Base (version A)

**URL:** https://www.waveshare.com/wiki/CM4-IO-BASE-A

| Dimensions | Details |
|---|---|
| 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 | 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 |

No. | Component | Description
-- | -- | --
1 | CM4 connector | Suitable for all versions of Compute Module 4
2 | DC power supply/programming interface | 5V/2.5A power supply, also can be used as an eMMC programming interface
3 | DISP Interface | MIPI DSI Display Interface
4 | FAN header | For connecting cooling fan, allows speed adjustment and measurement, only supports 5V fan.
5 | CAM Interface | Dual MIPI CSI camera interface
6 | HDMI0 Interface | HDMI Interface, Support 4K 30fps output
7 | USB 2.0 Interface | 2-channel USB 2.0 Interface, for connecting sorts of USB devices
8 | Gigabit Ethernet | Gigabit Ethernet RJ45 connector, with 10 / 100 / 1000M network support
9 | M.2 indicator | Indicating the operating status of M.2 interface
10 | ACT indicator | Raspberry Pi operating status indicator
11 | PWR indicator | Raspberry Pi power indicator
12 | BOOT selection | Jumper shorted: CM4 would be booted from USB-C interface Jumper opened: CM4 would be booted from eMMC or Micro SD card
13 | 40PIN GPIO header | Conveniently connect various HAT modules
14 | Micro SD Card Slot | For connecting a Micro SD card with a pre-burnt image (Lite variant ONLY).
15 | HDMI1 interface | HDMI1 Interface, Support 4K 30fps output
16 | USB 2.0 connector | Can be connected through an adapter
17 | FE1.1S | USB HUB chip, expanding one USB port to 4x ports
18 | M.2 Interface | Supports sorts of NVME SSD, or communication modules with PCIE M.2 KEY-M interface

## CM4 I/O Base (version B)

**URL:** https://www.waveshare.com/wiki/CM4-IO-BASE-B

The major difference is RTC battery and circuitry on the bottom, visible on 2nd image

| Dimensions | Details |
|---|---|
| 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 | 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 |

No. | Component | Description
-- | -- | --
1 | CM4 connector | Suitable for all versions of Compute Module 4
2 | DC power supply/programming interface | 5V/2.5A power supply, also can be used as an eMMC programming interface
3 | DISP0 interface | MIPI DSI Display Interface, DISP0 interface
4 | FAN header | For connecting cooling fan, allows speed adjustment and measurements, only supports 5V fan.
5 | CAM interface | Dual MIPI CSI camera interface
6 | HDMI0 interface | HDMI Interface, Support 4K 30fps output
7 | USB 2.0 interface | 2-channel USB 2.0 Interface, for connecting sorts of USB devices
8 | Gigabit Ethernet | Gigabit Ethernet RJ45 connector, with 10 / 100 / 1000M network support
9 | M.2 indicators | Indicating the operating status of the M.2 interface
10 | ACT indicators | Raspberry Pi operating status indicator
11 | PWR indicators | Raspberry Pi power indicator
12 | BOOT selection | jumper connected (ON): CM4 would be booted from USB-C interfacejumper not connected (OFF): CM4 would be booted from eMMC or Micro SD card
13 | 40PIN GPIO header | Conveniently connect various HAT modules
14 | Micro SD card slot | For connecting a Micro SD card with a pre-burnt image (Lite variant ONLY).
15 | HDMI1 port | HDMI1 port, Support 4K 30fps output
16 | USB 2.0 interface | Can be connected through an adapter
17 | FE1.1S | USB HUB chip, expanding one USB port to 4x ports
18 | M.2 connector | Supports sorts of NVME SSD or communication modules with PCI-E M.2 KEY-M interface
19 | RTC | PCF85063 chip, Allows RTC-related functions like wakeup, shutdown, reboot, and more
20 | RTC interrupt pin switch | PI-RUN: CM4 reboot on RTC interruptionGN-EN: CM4 shutdown on RTC interruptionD4: D4 pin is triggered on RTC interruption
21 | EMC2301 | Fan controller, for speed adjustment/measurement
22 | RTC battery socket | Can be connected to CR1220 button battery

JaredC01, 2025-01-22:
@geerlingguy do you have any of these I can use for measurements?

geerlingguy, 2025-01-22:
I have one sitting on the desk in front of me — note that the hole locations and sizing matches the Pi 4/Pi 5 practically the same, it just needs a little extra bottom height for the extra goodies there.

geerlingguy, 2025-01-22:
5mm seems like it would work fine, though you could go to 6-7mm for a little extra clearance (to keep any hot NVMe SSDs from heating the printed surface too much).

Alternatively, you could do cutouts or at least indents into the printed part for the NVMe or other taller components.

JaredC01, 2025-01-22:
> 5mm seems like it would work fine, though you could go to 6-7mm for a little extra clearance (to keep any hot NVMe SSDs from heating the printed surface too much).
>
> Alternatively, you could do cutouts or at least indents into the printed part for the NVMe or other taller components.

Thanks! I'll see what a cutout looks like behind it, and whether or not I can do a dual-mount version!

JaredC01, 2025-01-24:
I've added a module for the WaveShare CM4-IO-BASE carrier(s), but it needs testing.  @shanduur and @geerlingguy if one of you wants to print the mount and let me know if their CAD model is accurate, namely on the front cutout fitment, I would appreciate it!  From their CAD model, it looks like the ports will be recessed a bit more than normal, but there's also ribbon connectors on the bottom, so I don't want to move the board forward any more than is necessary.  The big concern is the HDMI port and seating fully with a cable plugged in.

Just for reference, I ended up making the spacing 7mm per @geerlingguy's note just to give some breathing room, and I also added a cutout on the back to access the M.2 drive with the carrier installed.  There's 2.85mm of space between the tallest component on the rear (the battery holder) and the base of the mount, so I expect there won't be any issues with fitment!

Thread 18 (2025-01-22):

Request for Intel Nuc BOXNUC8i5BEK2

bemany, 2025-01-22:
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

 _Originally posted by @bemany in [#10](https://github.com/JaredC01/LabStack/issues/10#issuecomment-2604327927)_

CodyKochmann, 2025-01-25:
+1 for a nuc8 option! It would be amazing to get those puppies vertical. The 4 screws along the bottom might be a better target to design a mount for than the provided nuc mount that makes the nucs footprint bigger.

JaredC01, 2025-01-31:
This will end up being part of the LabStack Rack repo - will cross-post there once ready.

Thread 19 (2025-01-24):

Module request. RPI5 + base nvme

fmurodov, 2025-01-24:
First thank you for this project.

I have Pi5 with Pimoroni nvme base. Is it any change to make module for this?

https://shop.pimoroni.com/products/nvme-base

JaredC01, 2025-01-24:
Module has been added to the Modules folder.  I used Pimoroni's CAD model, and their standoff height listed in the product page (7mm) for the spacing.  You will need to put screws thru the back of the mount into the 7mm spacers, then screw the Pi in from the top to the spacers.

Let me know if it fits, and if there's any questions or issues!

fmurodov, 2025-01-25:
I think the front panel needs to be flipped 180 degrees because the recesses for the NVMe board are currently on top of the PI instead of at the bottom.

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

JaredC01, 2025-01-25:
> I think the front panel needs to be flipped 180 degrees because the recesses for the NVMe board are currently on top of the PI instead of at the bottom.
>
> 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

Ah! I forgot to check clearance there! I'm not used to bases yet. 😅

The above is for adding a HAT still,  but if the Pimoroni base needs a bit of extra, I'll extend it. Give me about 30 minutes and I'll have a new version for you!

JaredC01, 2025-01-25:
Updated version pushed to the repo.  Let me know how this one goes, but it should fit just fine!

fmurodov, 2025-01-25:
Perfect. Thanks a lot!

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

fmurodov, 2025-01-25:
Perfect. Thanks a lot!

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

Closed 2025-01-25.

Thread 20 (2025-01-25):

Module Request - Support project tiny/mini/micro

CodyKochmann, 2025-01-25:
This project is amazing. Thank you for pursuing it!

It would be amazing to see if you guys could integrate the lenovo, hp, and dell 1 Liter boxes discussed in ServeTheHome's project tiny/mini/micro.

Not only would it open up a ton of options for the second hand market but you'd probably get a shout out from STH's channel since hes been carrying the endeavor for years.

Heres the link to the project's high level description where you can get the base model info.
https://youtu.be/bx4_QCX_khU?feature=shared

JaredC01, 2025-01-30:
Hey Cody!

I've followed Patrick's progress on this over the years myself!  The only reason I haven't put anything together yet is because these little machines are still relatively heavy for their size, and heavier objects don't pair well with 3D printed parts in many cases...  The safest bet for these machines is using a metal shelf, though I can definitely see about adding a "beauty plate" front fascia that would allow the machines to blend in with the rest of the aesthetics...  Would that fit what you're hoping to accomplish?

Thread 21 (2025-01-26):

Module request: NanoKVM lite

japz, 2025-01-26:
Thank you for starting this project, it's amazing!

I suggest a new module for the [NanoKVM lite](https://github.com/sipeed/NanoKVM?tab=readme-ov-file
). It's very small, two will certainly fit in a slot, and it might even be possible to squeeze three or four in. It would pair nicely with the Radxa X4 - the USB and HDMI can be routed behind the panel and the ethernet port could face out.

It is basically a LicheeRV board and there are some drawings and 3d files of the Lichee Nano board available via: https://cn.dl.sipeed.com/shareURL/LICHEE/LicheeRV_Nano.
I think there would need to be a small cutout on the bottom for the heatsink of the chip.

JaredC01, 2025-01-28:
I'll see what I can do.  The CAD for the LicheeRV doesn't include the HDMI port, so I would ideally need some measurements from the NanoKVM directly, at least with spacing from the bottom of the HDMI port to the top of the PCB or USB-C port.

japz, 2025-01-29:
Thanks! Here you go:
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

Let me know if you need any additional measurements.

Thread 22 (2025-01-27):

Ubiquity Toolless Rack Mount

JOLLY6R33NGIANT, 2025-01-27:
A mount for the ubiquity rack with room for a couple jetkvms, Rpi5s and some keystone cutouts I think would be nice.

JaredC01, 2025-01-27:
Just so I'm clear, do you mean the toolless 19" Ubiquiti rack? https://store.ui.com/us/en/products/toolless-mini-rack

With the way their rack system works, there are no rack ears, which means mounting would be basically impossible with a traditional design.  While I won't rule it out, I don't think this will end up being supported.

JOLLY6R33NGIANT, 2025-01-28:
Yeah that’s the one. I saw someone in the jet discord post about something similar so I thought it was worth a shot bringing up here.

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

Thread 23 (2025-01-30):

Fusion 360 Share link or STEP Files

nlj007, 2025-01-30:
This may exist somewhere, but I can't find it. Would it be possible to share this CAD data via a Fusion link as shown [in their documentation](https://help.autodesk.com/view/fusion360/ENU/?guid=ASM-SHARE-DESIGN)?

I have not been able to open the .f3d file in Fusion, and all resources online point to sharing a link to be the best way.

If sharing the native file this way is not an option, a non closed-source filetype such as parasolid (.xt) or STEP would be much appreciated. STL's are much less friendly to work with in parametric modelling software (SolidWords, OnShape, Fusion).

For reference, I am hoping to import most of these designs to OnShape and share them publicly for others to access and modify.

JaredC01, 2025-01-30:
I have no plans to share via link because I'm doing a lot of prototyping and addition of new models, and the link would point to the latest save, so there's a very real chance that people may download half-finished models.  The full F3D file shouldn't have any issues opening in Fusion, and I just tested downloading and opening it myself, which worked fine.  The file is rather large, so if you're having trouble loading it, it's likely due to the components included (namely the Pi models since they have a ton of components).  Give it a bit of time if your machine isn't super powerful, but it should load.

I had originally exported a STEP file, but the file size was too large to upload to GitHub without pushing it to a large-file repository, and I'm currently working on separating out the LabStack modules and mounts from the rackmount items that are compatible with LabStack (which I'm calling LabStack Rack) to make the CAD files smaller.

Once the repo's have been updated with everything, I'll have STEP files for everything, but in the meantime, I would try the Fusion file again, giving your machine time to load it.

JaredC01, 2025-01-31:
CAD updated, including simplifying all of the Pi and board models to save space.  STEP file was still too large to upload directly, but being text-based, I was able to compress it into a ZIP file.  Download and unzip for the full STEP.

Closed 2025-01-31.

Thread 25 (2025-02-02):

Can't find the file

Reedith, 2025-02-02:
I'm able to find all the files for the raspberry pie and jet kvm modules, but I can't find the file for the actual rack piece that holds them that you can make out of plastic or aluminum. Would love to 3D print one. is the file in here?

JaredC01, 2025-02-02:
The files for the 10" 3D printed version are in the LabStack Mini / STLs folder. The Modules are separate from the brackets.

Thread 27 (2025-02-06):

120mm fan Panel

laplansk, 2025-02-06:
Jared,

I see that there is a panel available for 80mm fans. Would you be able/willing to adapt to create a similar one for 120mm fans? I have several Noctuas laying around that I'd like to put to use rather than purchasing new 80mm fans. I also think that it will be nice to get air flowing full-width of the rack with two side-by-side 120s. They are admittedly just a tad too wide for the rack when side-by-side, but it looks to me like this could be accounted for by either including standoffs in the model so that they can be mounted on the inside of the case OR just mounting them on the outside of the panel. (If that wasn't clear, I can try to draw what I am describing and attach it to this Issue or we can have a quick chat about it). This whole thing is an excellent project. I am in the middle of printing the drawer now and really excited to get my homelab set up all tidy.

Cheers and thank you for considering.

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

JaredC01, 2025-02-06:
I'll take a look in CAD and see if anything makes sense... 2x 120's certainly won't fit inside the rack, but I may be able to do something clever to make them work as the picture shows externally.

laplansk, 2025-02-06:
Appreciate you looking into it.

For context, this is what I was imagining when I said inside. 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

Looking at how the screw holes on the fans would line up, I suppose you'd probably have to mount the panel on the inside to make it work, but it _could_ work, right?

JaredC01, 2025-02-06:
Without access to the mount holes on the fans, it would be hard to install that way. Off the top of my head, the best solution to make the internal idea work would be to make a plate that the fans mount on and sits internally, then make an external plate that can interface with the internal plate... I'm not sure whether that will work though, as the screws for the front panel would interfere with the fans.

I should have some time later tonight or tomorrow night to take a closer look at this and see what I can decide on.

JaredC01, 2025-02-09:
Just keeping this up to date... I haven't had time to poke at this at all.  I'll update you when I get some time!

laplansk, 2025-02-18:
@JaredC01,

I am new to CAD (basically 0 experience), but wondering if there is a intro/primer course you might want to point me to in case I can ramp up quickly and take a shot at modifying the existing 80mm fan chassis/[anel myself. Let me know! This is a skill I would like to acquire and I'd love to contribute!

JaredC01, 2025-02-18:
I'm sure there are plenty of good references available, but I learned most of what I know just by googling what I was trying to do.  Send me a DM on Discord if you have it, I'll see if I can help you out any...  I do still have this on my radar, but have been swamped with work from starting a new position.

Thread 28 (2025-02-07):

Organized list for which files correspond to which project?

xksteven, 2025-02-07:
Because it's my first time building one of these and I consider myself a noob I worry that I'll be picking the wrong file or stl file when sending it off to be made.  To be clear I'm considering this frame: [GeeekPi / DeskPi RackMate T0](https://amzn.to/4iIBsZ6)

It'd be nice to have a list (for example for your build).  I used these 4-5 files.

I don't know which of these two to get?
* [20M3x4x5mm](https://github.com/JaredC01/LabStack/blob/main/LabStack%20Mini/STLs/2U%20Mini%204x%20LabStack%20Module%20M3x4x5mm%20Heatset%20Bracket.stl)
OR
* [M3x3x4.6mm](https://github.com/JaredC01/LabStack/blob/main/LabStack%20Mini/STLs/2U%20Mini%204x%20LabStack%20Module%20M3x3x4.6mm%20Heatset%20Bracket.stl)

I think the JetKVM file is another directory?

* [JetKVM](https://github.com/JaredC01/LabStack/blob/main/Modules/STLs/Module%201x%20JetKVM.stl) (With a few variants for orientation or 2.)

JaredC01, 2025-02-09:
It is all a bit of a mess at the moment... I've been working on adding modules rather than getting the documentation done (with my thought being that I would make some documentation for each module).

For the printed bracket, the "normal" heatset inserts I've suggested (info over on the LabStack Rack repo, formerly JetKVM repo) are M3x4x5 (M3 thread, 4mm deep, 5mm wide).  I recently merged a PR that added the CNC Kitchen "shallow" heatsets that are M3x3x4.6 (M3 thread, 3mm deep, 4.6mm wide).  Chances are you will want the M3x4x5 version.

All of the modules are in their own directory as they can be used with both LabStack Mini (the 10" version) and LabStack 19 (the full rack version).  The separation between the modules and brackets will remain after cleanup, just for recorrd.

axiopaladin, 2025-02-10:
Personally I think some initial documentation would be the single biggest upgrade to this project right now. It doesn't have to go into full detail with specialized assembly instruction and everything; just a BOM and one-sentence description for each model would be a great help to getting started. Are there any docs or notes anywhere that we could reference to figure that out? I can try putting a PR together with a basic structure for things if that would help.

JaredC01, 2025-02-11:
I 100% agree with you (and it's well past due!).  I should have some time tomorrow or Wednesday to at least get a rough initial set of instructions set up.  From there, I'm open to updates as needed!

axiopaladin, 2025-03-01:
Are the any updates to share on the timeline for this?

itsCARLsanity, 2025-03-07:
@axiopaladin see Issue #42

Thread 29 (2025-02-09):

Radxa x4 mounts

wmblue, 2025-02-09:
I can't tell how you're mounting the Radxa x4 to the 3d printed plate mounts?

can you show me how you're mounting it with pictures, as well as what hardware/screws you might have needed to mount it?

Thanks!

JaredC01, 2025-02-09:
You need one set of spacers (either the PoE HAT spacers, or the longer ones if not using the PoE HAT), then it goes together backwards (screws through the back of the mount).  The screws are M2.5x25mm (head type doesn't matter)

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

wmblue, 2025-02-09:
Awesome! ty!

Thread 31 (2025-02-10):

Double-width bracket and Flex ATX PSU Module

adamhl8, 2025-02-10:
First of all, this is an awesome project. It works beautifully.

I wanted a way to mount my [Flex ATX PSU](https://www.amazon.com/dp/B08J2NDBWY), so I made a couple of models and thought they might be useful to others.

I modified the [existing bracket](https://github.com/JaredC01/LabStack/blob/main/LabStack%20Mini/STLs/2U%20Mini%204x%20LabStack%20Module%20M3x4x5mm%20Heatset%20Bracket.stl) to hold a "double-width" module:

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

STL here: https://github.com/adamhl8/share/blob/main/LabStack%20Double-width%20Bracket.stl

And then here's a module that holds a standard Flex ATX PSU:
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

STL here: https://github.com/adamhl8/share/blob/main/LabStack%20Flex%20ATX%20PSU%20Module.stl

Using this in my RackMate T1:

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

JaredC01, 2025-02-11:
Awesome!  Glad to see others taking the idea and making it their own!

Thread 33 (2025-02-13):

LabStack/Modules/STLs /Module 1x Pi with 25 SSD

OregonGunslinger, 2025-02-13:
Would it be possible to add pass-thru holes in the bottom plate so that screws can be installed from underneath to attach the pi?

JaredC01, 2025-02-13:
Pretty sure I understand what you mean, but just to clarify, you need access to the Pi's mount holes through the SSD's plate, correct?

https://github.com/JaredC01/LabStack/blob/main/Modules/STLs/Module%201x%20Pi%20with%2025%20SSD.stl

OregonGunslinger, 2025-02-13:
Exactly.  Thank You.

JaredC01, 2025-02-13:
Added 4mm holes through the SSD bracket and updated the original file with changes (updated in my last link).  If that's it, I'll close the ticket!

OregonGunslinger, 2025-02-13:
That's perfect for this one.  I have another ask (different situation) but I can open a new issue.

OregonGunslinger, 2025-02-22:
Follow up, if the new holes could be 6mm, that would help fit screws with slightly larger heads. The screws I'm using are 5.54mm.

Closed 2025-02-13.

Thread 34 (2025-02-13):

Module 1x Pi with POE and SSD

OregonGunslinger, 2025-02-13:
I have a Pi4 with:

GeeekPi Isolated PoE HAT for Raspberry Pi 4
https://www.amazon.com/dp/B08CVDQWXF
-and-
GeeekPi M.2 NVME SSD Storage Expansion Board for Raspberry Pi 4
https://www.amazon.com/dp/B0CBJYWKJ1

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

Would it be possible to create a tray for this?

JaredC01, 2025-02-13:
I'll see what I can do.  Can you get me the standoff size on both the NVMe base to the bottom, and the NVMe base to the Pi?  They look to be the same size, but I'd like to verify.

OregonGunslinger, 2025-02-13:
Without getting the calipers, I'm showing that both are 1/4 inch standoffs.  Note that in the picture, the mount for the NVMe is wrong and should be a bit shorter  but that shouldn't affect the part.

JaredC01, 2025-02-13:
> Without getting the calipers, I'm showing that both are 1/4 inch standoffs. Note that in the picture, the mount for the NVMe is wrong and should be a bit shorter but that shouldn't affect the part.

They're usually marked in mm rather than inches, which means they're either 6mm or 7mm (with 1/4" being closer to 6mm).  If you get a chance to verify that, please do.  I've seen 7mm standoffs pretty commonly, but not often for 6mm (and being 1mm off means the ports in the plastic won't line up).

I'm not sure what you mean by the mount for the NVMe is wrong; are you referring to the standoffs on that side?

OregonGunslinger, 2025-02-13:
Yes, the standoff.  In the image, the NVMe drive is angled funny and shouldn't be.  I'll get the calipers and supply a precise measurement for the other standoffs.

OregonGunslinger, 2025-02-13:
Sorry to muddy the waters.  The NVMe standoff is too long so the drive is offset too much on that end.  I do have a shorter standoff that will true it up.

The pi standoffs are 7mm by the micrometer.

JaredC01, 2025-02-13:
Good to know on the Pi Standoffs!  For the standoff from the NVMe base, I can model my own "standoffs" with the printed part.

If 7mm works with your current setup, I might as well leave the 7mm spacing (it's also what's currently on the WaveShare CM4 IO board, so an easy transfer).

I don't see any sort of CAD for the board design, so I will need to do some testing on spacing between the USB port on the base and the USB port on the Pi...  Are you able to get a measurement for me between the USB-A to USB-A ports on both the insides and the outsides?  Basically the inner part of the U and the outer part of the U...  That will get me the dimensions for where the USB port needs to be in the cutout!

OregonGunslinger, 2025-02-13:
Pardon my lack of drawing skills...  I hope this helps:

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

JaredC01, 2025-02-13:
That's perfect, thank you!

DerAndereAndi, 2025-03-14:
I'd like to share some thoughts on getting such a setup work with small hacky modifications of a current module.

I added a negative part to extend the opening of the "Module 1x Pi with HAT" vertically to the top and use the distance elements (same as in the images) to mount them. One problem turned out to be to bottom extension board for the SSD being a bit longer to the front side compared to the Raspberry Pi board. And secondly my "PoE HAT (C)" from waveshare is a bit taller so I can't slide it in easily. I have to detach the PoE HAT for now and reattach it. So getting the whole setup more closely to the bottom would be helpful in general. E.g. by not having to use the distance pieces at the bottom and there safe some vertical space and the NVME still have some space "to breath" :)

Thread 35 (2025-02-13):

Bracket Module Suggestion for the Radxa Penta SATA Hat (Raspberry Pi 5)

Ash-Bash, 2025-02-13:
I have a Radxa Penta SATA Hat for Raspberry Pi 5, and would like the ability to Mount it inside The DeskPi Rackmate T0, would be useful for anyone who's making a NAS Server Rack. Ive provide a Image of what the Hat looks like on the Raspberry Pi and a Link to their official page for the hat (For the Specs etc).

[Radix Penta SATA Hat Official Page](https://radxa.com/products/accessories/penta-sata-hat)

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

JaredC01, 2025-02-13:
What's the expectation for integration here?  Are you thinking about a LabStack module, or just some sort of option for mounting it with 4 drives in a mini rack?  I assume you would be looking for something OTHER than a LabStack module, mainly because there's not enough room for the drives to mount, but figured I would verify the intent!

Ash-Bash, 2025-02-13:
> What's the expectation for integration here? Are you thinking about a LabStack module, or just some sort of option for mounting it with 4 drives in a mini rack? I assume you would be looking for something OTHER than a LabStack module, mainly because there's not enough room for the drives to mount, but figured I would verify the intent!

To make a mini NAS server, Describing it to the best of my ability, the Hard Drives would be on a separate shelf/level from the raspberry Pi on the rack, they'd be laying flat in their own hard drive trays plan is for 5 hard drives in 2 stacks, but I am using the Hard Drives DeskPi's Official Solution for the Mounting of the Hard Drive Trays for the time being.

Ash-Bash, 2025-02-13:
> Okay, so my next question would be, how are you breaking out the SATA from the HAT to another shelf? I'm trying to get a full layout in my head of how this is going together so that I understand whether this would work as a LabStack Module or not.

The plan is to use SATA Data+Power Combo Extension Cables To & From the Hat & Hard Drives, I guess the Raspberry Pi could go Sideways like other Modules, the cables wouldn't need to come out of the front, since the cabling would be routed to the back of the hard drives since the connector would inwards so to speak, the ESATA port is the outlier here, where it would need to be threaded back into the rack they do provide a ESata to SATA Data+Power Cable.

HAT has a few Power Options A ATX Power Supply Interface and a Power Barrel Jack, but that would be a Internal too.

JaredC01, 2025-02-13:
Okay, I'm on the same page now!  The cabling for the drives will probably still be a bit too tall for a module, but we can try going that route and see what happens.  This is a similar setup to what I had here:

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

I eventually moved to slim cables, but still ended up being too tall (you had to install the module into the LabStack bracket before installing the bracket).

I'll see what I can do.

HalmSascha, 2025-02-14:
I thought about almost the identical use case and maybe there would be a solution for it. If there would be a bracket like the 2U Mini 4x LabStack Module M3x3x4.6mm Heatset Bracket with only one hole for a LabStack Module on the right side, the RasPi5 with the Radxa Penta SATA Hat could be mounted horizontally with a new/customized LabStack Module (Module 1x Pi with 25 SSD where the eSATA connection can be used. So there would be enough space for the 4 mounted SSDs horizontally and an additional 2.5 SSD connected with the eSATA-Port.

Ash-Bash, 2025-02-14:
> I thought about almost the identical use case and maybe there would be a solution for it. If there would be a bracket like the 2U Mini 4x LabStack Module M3x3x4.6mm Heatset Bracket with only one hole for a LabStack Module on the right side, the RasPi5 with the Radxa Penta SATA Hat could be mounted horizontally with a new/customized LabStack Module (Module 1x Pi with 25 SSD where the eSATA connection can be used. So there would be enough space for the 4 mounted SSDs horizontally and an additional 2.5 SSD connected with the eSATA-Port.
>
> What I don't know at the moment is whether the 4 horizontally mounted SSDs could be too heavy for the LabStack module.

Yeah, that’s what my concerns would be for packaging reasons I decided that the hard drives will be on another shelf, and use the lab stack shelf for other raspberry pis / kvms. Since I’m interested in also have docker images running too, to run other auxiliaries systems, like personal git server, homebridge etc

JaredC01, 2025-02-14:
Looking at this with a set of fresh eyes this morning, I have a couple of additional challenges that make me wonder if it's not worth using another solution (like the NVMe to SATA adapter setup I posted above)...

The hardest things to work around / problems that need solving that I can see so far are as follows...
* For a LabStack Module, the SATA cables will likely be too tall, meaning the slot next to the module would be unused with a blank cover, and you'll likely have to assemble the LabStack bracket and module together before putting it into the rack.  This isn't a dealbreaker, but it makes reusing that slot(s) hard.
* The Molex connection for power likely won't be usable as it's too close to the front of the Pi and would likely also end up being too tall.  So long as you're using the barrel jack instead, this should be okay.
* The eSATA connector will absolutely have to come out of the front of the panel before going to the drive (not necessarily an issue, but not "clean".

Here was my Pi 5 + PoE/NVMe HAT with M.2 to SATA adapter installed in a LabStack Mini...  You can see it "works" but it cuts into the module next to it.

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

What I ended up doing with my rack was setting up an M.2 extender to put the M.2 to SATA adapter back further in the rack so that all of my LabStack Mini slots were usable.

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

I don't have an issue continuing on this if that's what you would like, but I think there's enough caveats for this specific HAT for this specific use-case that it would likely be better used in a standalone NAS setup rather than in the LabStack / Mini Rack ecosystem...

Let me know if you want to continue with this specific setup, or if you have any questions about alternative options...

HalmSascha, 2025-02-16:
From my point of view and looking at my use case I'd go with a standalone NAS. But thank for sharing your thoughts on this.

Welved, 2025-05-07:
Question on that RaspberryPi 8 bay 2U. Is each of those bays able to accomidate a hackergadget PoE + NVME hat (https://hackergadgets.com/products/nvme-and-poe-hat-for-raspberry-pi-5)? Also, where would I go to locate that 8 bay 2U Pi solution?

JaredC01, 2025-05-08:
> Question on that RaspberryPi 8 bay 2U. Is each of those bays able to accomidate a hackergadget PoE + NVME hat (https://hackergadgets.com/products/nvme-and-poe-hat-for-raspberry-pi-5)? Also, where would I go to locate that 8 bay 2U Pi solution?

Are you looking for a mini rack or full-size rack?

For the Pi's, all of the mounts should be able to accommodate those HATs from looking at the visuals, but it would be worth verifying with one before going whole ham (as they say) with 8 of them.

Welved, 2025-05-08:
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

I already have a deskpi 10 inch 8U, I was just wondering if a bay could accomidate a hackgadget PoE + NVME hat, as that is what I have.

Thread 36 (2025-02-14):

Fan setup

alikaragoz, 2025-02-14:
Hey Jared, I was curious about your fans setup. Can you share some info about the model you used and how you wired them to the pi? 🙏🏻

JaredC01, 2025-02-14:
Absolutely!  For the fans, I used a set of Arctic Cooling 80mm fans: https://www.amazon.com/dp/B07XL9QJHF

The fans themselves are powered by the PoE + NVMe HAT that I have on my Pi 5, which has headers for 3v3, 5v, and 12v (Dupont connectors), but you can grab 5v power from just about anywhere to run them.  They work very well at 5v, and are nearly silent while pushing/pulling what I consider to be a "lot" of air.

Here's the PoE + NVMe HAT I used: https://www.amazon.com/dp/B0D8JC3MXQ

You can see the pin headers in the corner, but you can also just use the 5v and GND pints from the 40-pin on the Pi if you aren't using a HAT that blocks them!

alikaragoz, 2025-02-14:
I’ll take a look at the Arctic fans; they’re also quite affordable in France.
I’d like to find a way to power both fans using a single USB port—I think a USB splitter could work.
I really appreciate all the time and resources you’re providing on this repo. Thank you 😇

Closed 2025-02-14.

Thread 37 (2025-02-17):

1U 10" rock5b

SorinAlexandruGaletuse, 2025-02-17:
Good morning, i have started to build my 8u rack and using a few of your excellent designs,  i have not a clue about designing in CAD , so my question is, can you build a 1U that will fit a rock5b board, with a bit of room for the nvme to be attached on the bottom so it will have a bit of space not to heat to much, also can you design it so the rock5b can be placed on the left or right side of the front unit? The reason for me will be that i have a pi4 cluster hat with 4 pizero2w that it we be on the bottom of this 1U but will go up on the next U. I don't know if that makes sense :).
Thanks

SorinAlexandruGaletuse, 2025-02-20:
I have found that a rock5b with poe hat can be fitted in a 1u, can anyone modify a 1u unit that was created by this guy , and put some support to attach the board and a front panel? Or just made the gap a bit higher by 1cm so it can fit . Thanks
Https://www.printables.com/model/1170708-modular-1010-inch-rack

GLiNet Rack Mount and 4 Port Patch Panel.stl

I cannot attach the link of the stl file, but it can by found under that name

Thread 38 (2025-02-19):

250mm build plate compatibility

emolitor, 2025-02-19:
I used the cut tool in the slicer to do this but if you shaved off the 2mm bezel from each side the model then has a width of 250mm which will improve compatibility without compromising strength IMO.

DunarDolorgiet, 2025-02-20:
If you rotate the 2U Mini model by 45° it will fit in a 242x242 area; giving you enough space for skirts/brims on a 250 print bed. If you want the layer orientation to match your other printed parts you can change the infill orientation by 45°. In Prusa/OrcaSlicer Print Settings -> Infill -> Advanced -> Fill angle.

jrad88, 2025-02-26:
What I did was set it to 100% infill, since the components are so small the extra beef adds good structure, and then the angle isn't important.

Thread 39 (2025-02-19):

Heat set inserts in module trays

ReillyB, 2025-02-19:
Quick question since I couldn't find pictures of the trays outside of the mounting plate. It looks like the modules have holes for heat set inserts but I am unclear as to how they are supposed to be used. Could a couple pictures of the modules from different angles be added to the ReadMe to illustrate how those heat sets are intended to be used? Maybe I'm just dense and missing the obvious use case lol.

ReillyB, 2025-02-19:
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

ReillyB, 2025-02-19:
AH, they're for the Pi5 active cooler pins aren't they? Welp, I'll close the issue since they're not for heatsets at all!

JaredC01, 2025-02-19:
> AH, they're for the Pi5 active cooler pins aren't they? Welp, I'll close the issue since they're not for heatsets at all!

Sorry for the late reply; you are absolutely correct!

Closed 2025-02-19.

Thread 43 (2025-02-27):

Module Blank with vents or fan

fxhart, 2025-02-27:
Any chance you can make a blank module that has venting holes on it?  Hexes seem to be the new hotness.  Also maybe a blank that can attach a small fan?

Thanks!

JaredC01, 2025-03-03:
Absolutely doable!  I'll add it to the list!  This week I hope to get a good bit of backlog done, but this may be next week before I can get to it.

fxhart, 2025-03-03:
Thanks!

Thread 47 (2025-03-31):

254mm lengs is to big for Prusa printers

Wii23Solo, 2025-03-31:
Hello and thank very you for the great 3D data!

Unfortunately the long parts are 4mm too long. I have a Prusa MK3 that can only print 250mm. I tried to shrink the models by 1.5% so that they would fit on my print bed, but then the recesses no longer fit.

It would be sooo great if the long parts were a little shorter then hobbyists could also join in with Prusa.

I'm also looking for a slot for PI5 and Geekworm X1200 5V UPS Shield + HAT - Is that anyhow possible?

Besties, Stefan

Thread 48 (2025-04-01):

Request for Documentation on Rackmount Standards & Dimensions

Axolito, 2025-04-01:
Hi,

First of all, thank you for this awesome project!

I was wondering if you could provide documentation outlining the design standards used in LabStack. Instead of measuring dimensions directly from STL or CAD files, it would be great to have a reference document explaining the key principles and dimensions to follow when designing compatible mounts.

A diagram or schematic showing the key mounting points, spacing, and overall constraints would be very helpful for contributors looking to create custom mounts.

Would it be possible to add such documentation to the repository?

Thanks for your work!

Axolito, 2025-04-01:
Thank you very much. There's no rush, I'll rely on the dxf files while waiting for the documentation.

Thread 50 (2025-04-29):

POE power delivery for router and switch

AdelaideBenson, 2025-04-29:
With your only power input being POE what does the setup for power to the router and switch look like?

AdelaideBenson, 2025-04-29:
thank you!

Closed 2025-04-29.

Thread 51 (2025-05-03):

One smaller hole diameter in 2U Mini 4x LabStack Module M3 Nut Bracket.stl

marcelblijleven, 2025-05-03:
Hi,

After printing I noticed one of the holes (bottom right corner) of the [2U Mini 4x LabStack Module M3 Nut Bracket.stl](https://github.com/JaredC01/LabStack/blob/main/LabStack%20Mini/STLs/2U%20Mini%204x%20LabStack%20Module%20M3%20Nut%20Bracket.stl) model has a smaller diameter.

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

Thanks for the modules!

JaredC01, 2025-05-05:
Good catch!  At least it's too small, so you can use a drill bit to enlarge it, but I'll definitely get that sorted!

Closed 2025-05-28.

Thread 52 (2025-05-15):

Unifi USW-Flex-Mini Module

BeM11B2P, 2025-05-15:
Thank you for all the modules you have been able to create. Is there any way to create one for the USW-Flex-mini switch?

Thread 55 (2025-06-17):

Rasberry Pi 5 PWM fan control?

ArmandBriere, 2025-06-17:
Hi there,

I'm searching for a way to control PWM fan speed with Raspberry Pi 5 GPIO pins, does anyone has some documentation on how they wired the fans to a Pi and how to control the speed with software?

Looking at the [2U Mini 2x 80mm Fan Panel.stl](https://github.com/JaredC01/LabStack/blob/main/LabStack%20Mini/Accessories/STLs/2U%20Mini%202x%2080mm%20Fan%20Panel.stl), it's intended to put fan in the case, but how do you power them?

Thx

JaredC01, 2025-07-21:
I'm not as much good with software as I am with hardware.  I just run the 12v fans at 5v (or 7v if you have a 12v and 5v output option).  The Arctic Cooling 80mm fans I'm using are basically silent at 5v and still move a decent amount of air, but you could also get a boost converter and use it to manually adjust the fan output voltage:

https://www.amazon.com/dp/B0CTY18R37/

Hook up the VIN + to the Pi's 5v GPIO, VIN - to Pi's GND GPIO, wire the fan to the output...

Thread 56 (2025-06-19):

Confused about the LabStack Mini

harveyz0, 2025-06-19:
Is there any documentation for the LabStack Mini files? I'm confused about if the nut bracket vs the heatset bracket? Can I just use the nut bracket as a single piece to hold my Pi with HAT module? Or do all the pieces in the LabStack mini make one bracket?

When I send an item to the lasers do I send the STL or the DXF file? Don't mind me I'm a software guy.

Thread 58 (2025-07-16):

Pimoroni NVME base with RP5

mmbcode, 2025-07-16:
New to 3D printing, and running into a bit of an issue with the pimoroni NVME base RP5 STL. My selected NVME's have large heat sinks requiring me to use 12MM offsets in place of the default 7MM that come with the base. Basically I need to move the IO shield rectangle up 5MM from its current location (in reference to the original base of the where the mounting of the device would occur. The DeskPI rack comes with a metal 2U mounting bracket that use centered thumb screw  (32-6) rather than the two holes on top and bottom per module as included in you STL.

Question part: I have been trying to make these changes to your posted STL and failing miserable. Rather than make a bunch of wrong turns is there a software you would recommend to make these changes? I was hoping it would be as simple as selecting the negative space and moving it around, but the programs I was attempting to do this tinkercad can't seem to ungroup things. Can you recommend a good software to make these changes to the STLs?

Thank you in advance for your time!

MMB

JaredC01, 2025-07-16:
I can make that happen... give me 24 hours and I'll have an option for you.

JaredC01, 2025-07-17:
Well, make that 48 hours, but we're good to go!  Added a "tall" version of the mount, to be used with 12mm standoffs rather than 7mm.

https://github.com/JaredC01/LabStack/blob/main/LabStack%20Modules/STLs/Module%201x%20Pi%205%20with%20Pimoroni%20NVMe%20Base%20Tall.stl

Closed 2025-07-17.

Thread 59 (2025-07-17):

2x Pi module - Base/HAT support question

dgmulholland, 2025-07-17:
Hey, awesome project!

I'm looking at building a high-density pi cluster and was hoping you could give an insight into the amount of space available in the 2xPi module for HATs or Bases? I want to put 8 Pi 5's in 2U using 4 of the the 2x Pi modules but need a little extra space for POE and storage.

My preferred solution would be the [Waveshare PoE M.2 HAT+ (B)](https://thepihut.com/products/poe-m-2-hat-b-for-raspberry-pi-5) as it supports full size NVMe and PCIe 3.0 speeds but it also sits on top of the front I/O and increases the total height. Looking at the STL am I right in assuming that anything outwith the volume of the Pi itself will cause issues?

JaredC01, 2025-07-17:
More or less correct... You have about 3mm of space above each Pi before you run into issues, and that HAT will absolutely take more space than that.  There's also the issue of mounting for both Pi's since they share a set of mounting holes, and the HATs use standoffs....  You would need to come up with something clever (like using a long M2.5 screw and cutting the head off of it?) to make it work there as well.

All that said, there's two options that @geerlingguy reviewed (https://www.youtube.com/watch?v=x9ceI0_r_Kg) that MIGHT work?  The HackerGadgets PoE + NVMe HAT, and the n|fuse PoE HAT with m.2:

https://hackergadgets.com/products/nvme-and-poe-hat-for-raspberry-pi-5

https://n-fuse.co/devices/SBCPoE-RPi-Power-over-Ethernet-Hat-for-Raspberry-Pi-5-with-mPCIe-Slot-m2-slot.html

The limitation there is that you have to use 2230 or 2242 NVMe drives, though 2230 drives in particular seem to be pretty readily available due to the increase in the handheld PC market.

JaredC01, 2025-07-21:
Standoffs with different lengths would work, but not everyone will want to spend extra on that, so I didn't want to assume you would do it the "right way" if you will.

Let me know if you get it working like you want - I'd love to see a cluster of Pi 5's with NVMe HATs and PoE.

dgmulholland, 2025-07-25:
I'm now wondering if the Radxa X4 SBC would be a good candidate for this thought experiment?
It's the same general footprint as the RPi, has a built-in NVMe connector and it's PoE HAT fits within the total volume of the device.

It drinks more power that the Pi that's for sure, and I don't know what the thermals would like considering the chip is on the base and won't have any sort of heatsink other than plastic and another N100 right next to it. I can see it thermal throttling badly.

Possibly a combination of the 1x Pi with HAT and the 2x Pi modules would work to give the required space but reduce the node count to 6? Have the 2x Pi modules on the left and right, then 2 1xPi + HAT modules back-to-back in the middle 2 slots.

JaredC01, 2025-07-25:
I have a Radxa X4 in my mini rack - with the heatsink it takes up a lot of space, and the heatsink is absolutely needed.  I think a Pi 5 with one of the hats above will probably be the best bet, and the n-fuse model is probably the best option of those two...  It's a unique situation - maybe a CM5 with a breakout board?

Radxa for reference:
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

dgmulholland, 2025-07-25:
That's a very interesting point... I think I'd written off a bunch of options because I wanted to use full length SSDs but that's not a requirement any more.

I found this from Waveshare which seems to be compatible with the official cooler:
https://thepihut.com/products/poe-hat-h-for-raspberry-pi-5-and-cm5

JaredC01, 2025-07-25:
Actually, the H model doesn't look like it will work - the transformer sticks down below the board quite a bit, and would interfere with the heatsink unless you pull off the fan:

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

dgmulholland, 2025-07-25:
I think I've looked at too many HAT's and my brain is a bit fried for a Friday afternoon but would the Waveshare PoE M.2 HAT+ work? Potentially with the tops of the GPIO pins clipped off to reduce the total height?

https://thepihut.com/products/poe-m-2-hat-for-raspberry-pi-5

JaredC01, 2025-07-25:
I don't THINK that one would work, even with the pins clipped, but this one might?  I don't think you can use the fan heatsink with either and keep the height needed, but you might be able to do the thinner heatsink that's out there and squish this guy on top of it...

https://www.waveshare.com/poe-m.2-hat-plus-c.htm

JaredC01, 2025-07-25:
The heatsink...

https://www.waveshare.com/pi5-active-cooler-c.htm

JaredC01, 2025-07-25:
I think I may order a pair of those HATs, heatsinks, and a couple of Pi 5's to test this myself...  It'll be a bit (going to order it from Waveshare directly to save on cost), but I'll let you know how it goes.  If you end up pulling the trigger and get the parts in before I do, let me know how it goes!

dgmulholland, 2025-07-26:
The only place I can see that version of the HAT in the UK is on Amazon (eugh). But I decided to just go ahead and grab it out of curiosity so I'll let you know how it goes and see if I can get some measurements for the total height of the stack

JaredC01, 2025-07-26:
Sounds good. I did end up ordering a pair myself from Waveshare directly, so I'll be testing at well once they arrive.

JaredC01, 2025-07-31:
Oh that's absolutely perfect!  It looks like the heatsink is installed under there as well?  Definitely a compact package - I'm waiting for mine to arrive, and I'll be able to test it in a single 2-Pi module if you can't get a module printed in the meantime, but I think it's going to be absolutely spot-on.

You may want to print one of the 2x 80mm fan 2U brackets and throw a couple of fans in it to cool the Pi 5's since there's not a lot of space for convective cooling.  I love the Arctic Cooling P8's for it - https://www.amazon.com/dp/B07XL9QJHF

Here's the bracket itself - https://github.com/JaredC01/LabStack/blob/main/LabStack%20Mini/Accessories/STLs/2U%20Mini%202x%2080mm%20Fan%20Panel.stl

JaredC01, 2025-07-31:
You're welcome! I'd love to see some pictures when you get it all together!

JaredC01, 2025-08-03:
Well, mine showed up today!  I've only got 1x Pi 5 at the moment (grabbing a couple more from Microcenter tomorrow), but I can say with 100% certainty that these will work in the 2x Pi mount.

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

geerlingguy, 2025-08-03:
Sheesh! How is cooling in there? Seems like a potential winner, as long as you print out of something that won't sag over time...

JaredC01, 2025-08-03:
You know, I may just put together a "vertical" 2x 80mm fan setup that fits in a 1U slot to blow up air from underneath... it may help with something like this, especially if the back of the rack is too far away to get good airflow (like a standard 19" rack).

JaredC01, 2025-08-03:
I may have gone one further...  Dual 4010 Blower fans, and single 4010 Axial fan options... Not sure yet where to get power from since the GPIO is a bit occupied, but that's a later me's problem.

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

dgmulholland, 2025-08-04:
Would a case fan fit on that mount point? I was thinking something like https://noctua.at/en/products/fan/nf-a4x20-pwm. The Noctua fans come with a 30cm extension cable which looks like it might be able to squash under the HAT.

JaredC01, 2025-08-04:
Alright, got the blowers in today - Looks like the USB-C PCB method works, but it is a bit tall.  You can still install it as it sits, but you have to rotate the module to a 45 degree angle to get the PCB through.

I'm reprinting a version with less gap between the Pi and the fans, and one that doesn't use heatset inserts, and I'll post a couple of pics when that's completed.  Once I'm happy with it, I'll release the files as well.

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

dgmulholland, 2025-08-07:
So I picked up a couple of fans specifically for the raspberry pi to try and get a plug-and-play option. The official cooler is too tall to have under the PoE hat (as expected), the regular 40mm fan and 30mm blower from the official cooler have cables that don't reach if they are placed at the back. But the 30mm blower marketed as a [replacement for the fan in the Argon Neo 5 case](https://thepihut.com/products/replacement-30mm-fan-for-argon-neo-5-case) looks like a reasonable option assuming it can move enough air to be effective.

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

JaredC01, 2025-08-07:
Interesting! Thank you for the research on this as well... the blower MAY be enough, but I will need to create a bracket for it.

Do you have a set of calipers by chance? I need to know how tall the fan is, what the opening size is for the fan output, hole sizes and locations, etc...

I may be able to find a generic 30mm blower model, but I'll have to look!

JaredC01, 2025-08-11:
Next update... The 3007 blower fans I ordered have arrived, but the cables are too short.  I wasn't able to find any other options that had a Pi 5 fan connector pre-installed on Amazon, but I can at least get a model made for the 3007 blowers for those that have options.

dgmulholland, 2025-08-13:
Good grief! Looks good though. I've ordered 2 new Pi 5s, heatsinks, and HATs to get my cluster started but I still need to get modules printed so I'm a bit behind you

Closed 2025-09-13.

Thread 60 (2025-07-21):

STL Request: Raspberry Pi with Dual Keystone Jacks

clowncracker, 2025-07-21:
Hi! I was wondering if you’d be open to helping me out with an STL file—just a simple Raspberry Pi mount with two keystone jacks. I don’t have any 3D modeling experience, and this is the last piece I need to finish off my mini rack setup. I’d really appreciate it!

clowncracker, 2025-07-21:
If two won’t fit, one will still work for my setup, just in case that helps.

JaredC01, 2025-07-21:
https://github.com/JaredC01/LabStack/blob/main/LabStack%20Modules/STLs/Module%201x%20Pi%20with%202x%20Keystone.stl

Here ya go!

Closed 2025-07-21.

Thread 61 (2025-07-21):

Mounting holes don't line up to DeskPi rack

Tohaker, 2025-07-21:
I have printed both https://github.com/JaredC01/LabStack/blob/main/LabStack%20Mini/Brackets/STLs/2U%20Mini%204x%20LabStack%20Module%20M3%20Nut%20Bracket.stl and https://github.com/JaredC01/LabStack/blob/main/LabStack%20Mini/Brackets/STLs/2U%20Mini%20Split%204x%20LabStack%20Module%20Bracket%20x2.stl (the latter is pictured) and neither of them fully line up with the (I'm hoping) standard screwholes on my DeskPi T1. The scale I'm printing them at is unchanged from the STL files, and the width is just fine, but the holes seem a whole quarter-U off.

Has anyone had the same issue? Do I need to just stretch the STL slightly or do the files need changing?

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

JaredC01, 2025-07-21:
You have them mounted in the wrong location... The top hole you don't have populated there is the first hole in the first 1U section, so you need to move the shelf above the LabStack bracket up 1 hole, then move the LabStack bracket up 1 hole as well...  I'd do the same with the lower brackets as well to make sure everything is aligned properly.

Tohaker, 2025-07-22:
That makes a lot of sense 🤦‍♂️ Thank you for pointing it out, I'll give that a go later!

Tohaker, 2025-07-22:
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

This worked a charm, thanks for your time to help me! And thanks for this repo, amazing work :)

JaredC01, 2025-07-22:
Awesome!  Those little 1/2U modules will get you sometimes!

Closed 2025-07-22.

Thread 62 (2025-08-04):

GL.iNet Comet

customade, 2025-08-04:
Hi, since we can't really get JetKVM in the US right now, I went down the [GL.iNet Comet](https://www.gl-inet.com/products/gl-rm1/) route. Could you add an adapter to work in one of the slots? I'll also see what I can do to try to modify one to work. It doesn't have screw holes for mounting so it will need to be braced a little better. Dimensions are 80mm long x 60mm wide x 18mm tall.

customade, 2025-08-13:
I took a crack at it in Fusion since I have one on hand. It fits really well. Super snug and doesn't move. I'll share the file. Though I probably need to make a left facing and a right facing port option. Also...this isn't as professional as yours so feel free to church it up.

JaredC01, 2025-08-13:
Looking forward to taking a poke at it!

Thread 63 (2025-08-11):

Jetson Orin Nano compatibility.

Cup0Pojeono, 2025-08-11:
Since this can have raspberry pis and the radxa x4, is there a way to be able to fix a jetson orin nano and maybe even a jetson orin nano super developer kit onto a module?

Cup0Pojeono, 2025-08-11:
Ok. Thank you for the quick reply!

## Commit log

2025-01-17 Initial commit.
    Push STLs and images.
    [1U 2x Keystone 2x SMA Left Mount.stl, 1U 2x Keystone 2x SMA Right Mount.stl, 1U 2x Keystone Left Mount.stl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]
2025-01-17 organization and add LabStack 19 folders + DXF
    [1U Mini 2x Keystone 2x SMA Left Mount.stl, 1U Mini 2x Keystone 2x SMA Right Mount.stl, 1U Mini 2x Keystone Left Mount.stl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]
2025-01-18 Add CAD and Split Mini Bracket
    [2U Mini Split Printed Bracket Brace x2.stl, 2U Mini Split Printed Bracket x2.stl]
2025-01-19 Create Module 1x Pi with 25 SSD.stl
    [Module 1x Pi with 25 SSD.stl]
2025-01-19 Add non-PoE HAT spacers for Radxa X4 module
    [Module Add Radxa X4 PoE HAT Spacer x4.stl, Module Add Radxa X4 Spacer x4.stl]
2025-01-20 Create Module 1x JetKVM 2x Keystone.stl
    [Module 1x JetKVM 2x Keystone.stl]
2025-01-20 Fixed rendering error.
    [Module 1x Pi with 25 SSD.stl]
2025-01-20 added M4 Mac mount and updated naming
    [1.5U Mini 1x M4 Mac Mini with 1x LabStack Bracket.stl, 2U Mini 4x LabStack Module Bracket.stl, 2U Mini Split 4x LabStack Module Bracket x2.stl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]
2025-01-20 fixed extra bits
    [1.5U Mini 1x M4 Mac Mini with 1x LabStack Bracket.stl, M4 Mac Mini Spacer x2.stl]
2025-01-20 add mirror for Mac mount
    [1.5U Mini 1x M4 Mac Mini with 1x LabStack Bracket Left.stl, 1.5U Mini 1x M4 Mac Mini with 1x LabStack Bracket Right.stl, 1.5U Mini 1x M4 Mac Mini with 1x LabSt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]
2025-01-20 updated m4 Mac mount
    [1.5U Mini 1x M4 Mac Mini with 1x LabStack Bracket Left.stl, 1.5U Mini 1x M4 Mac Mini with 1x LabStack Bracket Right.stl, M4 Mac Mini Spacer x2.stl]
2025-01-21 Fix clearance on split bracket
    [2U Mini Split 4x LabStack Module Bracket x2.stl]
2025-01-21 Fixed orientation
    [2U Mini Split 4x LabStack Module Bracket x2.stl]
2025-01-24 Add WaveShare CM4-IO-BASE and fix geometry on HAT mounts
    [Module 1x Pi 5 with WisdPi 5Gbps HAT.stl, Module 1x Pi with HAT.stl, Module 1x WaveShare CM4-IO-BASE with HAT.stl]
2025-01-24 fix geometry
    [Module 1x WaveShare CM4-IO-BASE with HAT.stl]
2025-01-24 fixed broken geometry
    [Module 1x Pi 5 with WisdPi 5Gbps HAT.stl, Module 1x Pi with HAT.stl, Module 1x WaveShare CM4-IO-BASE with HAT.stl]
2025-01-24 add Pimoroni NVMe base, fix Pi opening on Pi modules
    [Module 1x Pi 5 with Pimoroni NVMe Base.stl, Module 1x Pi 5 with WisdPi 5Gbps HAT.stl, Module 1x Pi with 25 SSD.stl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]
2025-01-25 Fix Pimoroni Base clearance and update cutout on HAT-capable mounts
    [Module 1x Pi 5 with Pimoroni NVMe Base.stl, Module 1x Pi 5 with WisdPi 5Gbps HAT.stl, Module 1x Pi with 25 SSD.stl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]
2025-01-25 Update 1U Mini 525 Drive Bay Mount.stl
    [1U Mini 525 Drive Bay Mount.stl]
2025-01-30 Create Module 1x Pi 1B Rev 2.0.stl
    [Module 1x Pi 1B Rev 2.0.stl]
2025-01-30 Update Module 1x Pi 1B Rev 2.0.stl
    [Module 1x Pi 1B Rev 2.0.stl]
2025-01-31 Create Module WaveShare 2.8in DSI Display.stl
    [Module WaveShare 2.8in DSI Display.stl]
2025-01-31 Update CAD, add STEP via ZIP
2025-01-31 Create Module 1x JetKVM 1x Keystone 90 Degree.stl
    [Module 1x JetKVM 1x Keystone 90 Degree.stl]
2025-02-03 Add 2U Mini Printed Bracket with 4mm holes for inserts
    [2U Mini Printed Bracket 4mm insert.stl]
2025-02-04 * 4.3mm hole width * Chamfer * 3mm hole depth
    [2U Mini Printed Bracket 4mm insert.stl]
2025-02-04 adjusted naming scheme
    [2U Mini 4x LabStack Module M3x3x4.6mm Heatset Bracket.stl, 2U Mini 4x LabStack Module M3x4x5mm Heatset Bracket.stl]
2025-02-12 Create Module 1x JetKVM with Logo.stl
    [Module 1x JetKVM with Logo.stl]
2025-02-12 added 2.5" SSD models
    [Module 2x 25 SSD.stl, Module 3x 25 SSD.stl]
2025-02-13 Update Module 1x Pi with 25 SSD.stl
    [Module 1x Pi with 25 SSD.stl]
2025-02-13 Update Module 3x 25 SSD.stl
    [Module 3x 25 SSD.stl]
2025-02-26 Create 2U Mini 4x LabStack Module M3 Nut Bracket.stl
    [2U Mini 4x LabStack Module M3 Nut Bracket.stl]
2025-05-28 Fixed screw hole diameter per Issue 51
    [2U Mini 4x LabStack Module M3 Nut Bracket.stl]
2025-05-28 Sorting update/upgrade for clarify
    [1.5U Mini 1x M4 Mac Mini with 1x LabStack Bracket Left.stl, 1.5U Mini 1x M4 Mac Mini with 1x LabStack Bracket Right.stl, 1U Mini 2x Keystone 2x SMA Left Mount.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]
2025-07-17 Create Module 1x Pi 5 with Pimoroni NVMe Base Tall.stl
    [Module 1x Pi 5 with Pimoroni NVMe Base Tall.stl]
2025-07-21 Create Module 1x Pi with 2x Keystone.stl
    [Module 1x Pi with 2x Keystone.stl]
2025-08-05 Added active cooling dual-Pi options
    [4010 Axial Mount.stl, Dual 4010 Blower Mount.stl, Module 2x Pi with 40mm Fan.stl]
2025-08-13 Add 30x30x7 blower fan option
    [4010 Axial Mount.stl, Dual 3007 Blower Mount.stl, Dual 4010 Blower Mount.stl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]
2025-11-28 Create Module 1x Waveshare 30915.stl
    [Module 1x Waveshare 30915.stl]
2025-12-17 Update Module 1x Waveshare 30915.stl
    [Module 1x Waveshare 30915.stl]
